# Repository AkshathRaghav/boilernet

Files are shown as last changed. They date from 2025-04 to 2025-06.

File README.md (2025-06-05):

# BoilerNet: A Compute-Enabled Mini-NAS

<div align="center" style="display: flex; justify-content: center; align-items: center; gap: 1rem;">
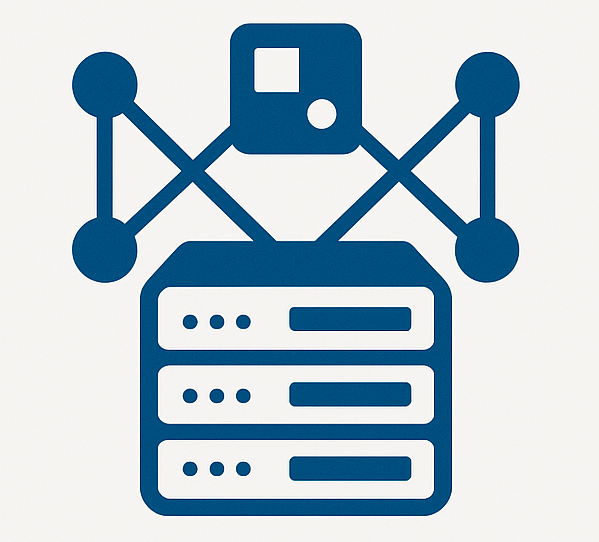
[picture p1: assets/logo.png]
  
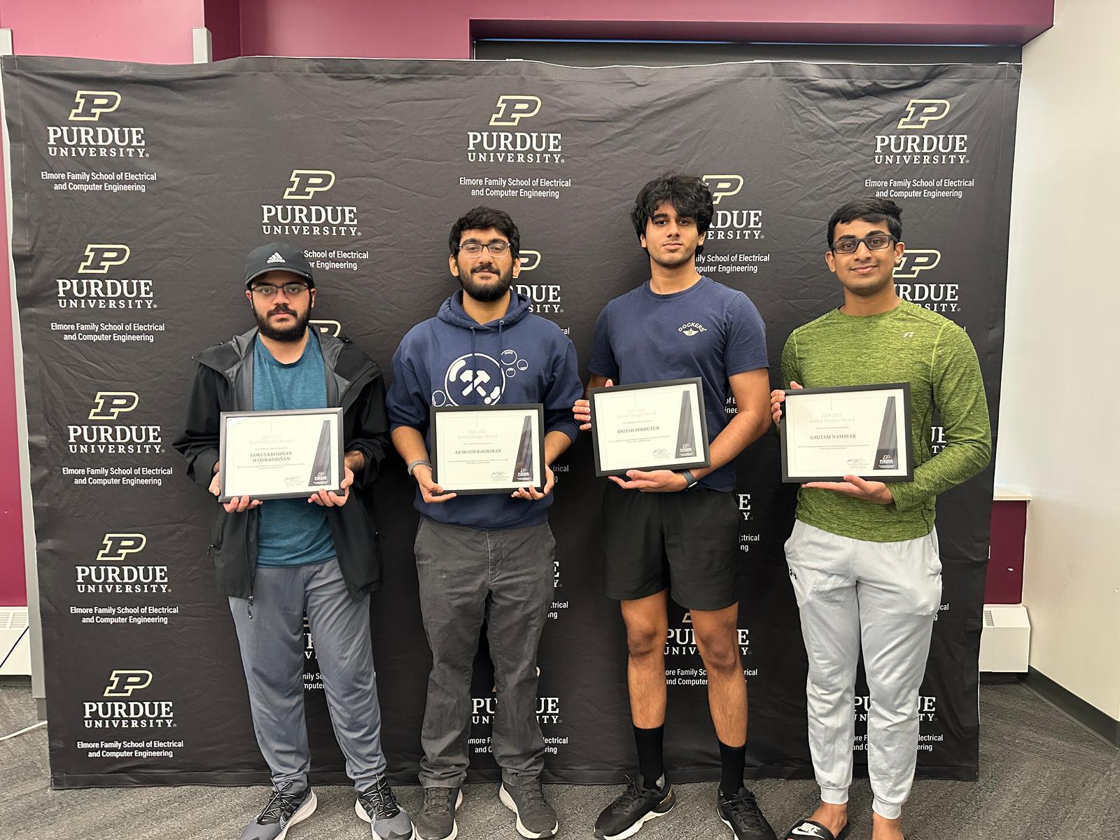
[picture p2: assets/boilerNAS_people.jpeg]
people
  
</div>

<div class="caption" align="center">
    BoilerNet Team 20! 
    From L to R: Gokulkrishnan Harikrishnan, Akshath Raghav Ravikiran, Aneesh Reddy Poddutur, Gautum Kottayil Nambiar
</div>

## Overview 

This project aimed to develop a Network Attached Storage utilizing ESP32 MCUs. The aptly-named BoilerNet aims to enable In-Network-compute alongside swappable disks and compute workloads, neatly brought together by a cloud-hosted Dashboard interface. There are a few core ideas that form the foundation for this ”cluster” – Low Power Usage, Plug-and-Play Workloads, High Scalability.

> Our reports/presentations are linked in the [/docs](./docs/). They contain in-depth views, reasonings and explanations regarding the design and its motivation. We also outline how we tested and ensured functionality. **This repository is just meant to help anyone who wishes to "refer" to our code/designs for their own use-case.**

> Watch the Demo that won us the "Senior Design Award" for Spring '25 through Purdue ECE: [Link](https://www.youtube.com/watch?v=jUlh9KClEwE)!

<div style="display: flex; justify-content: center; align-items: center; gap: 1rem;">
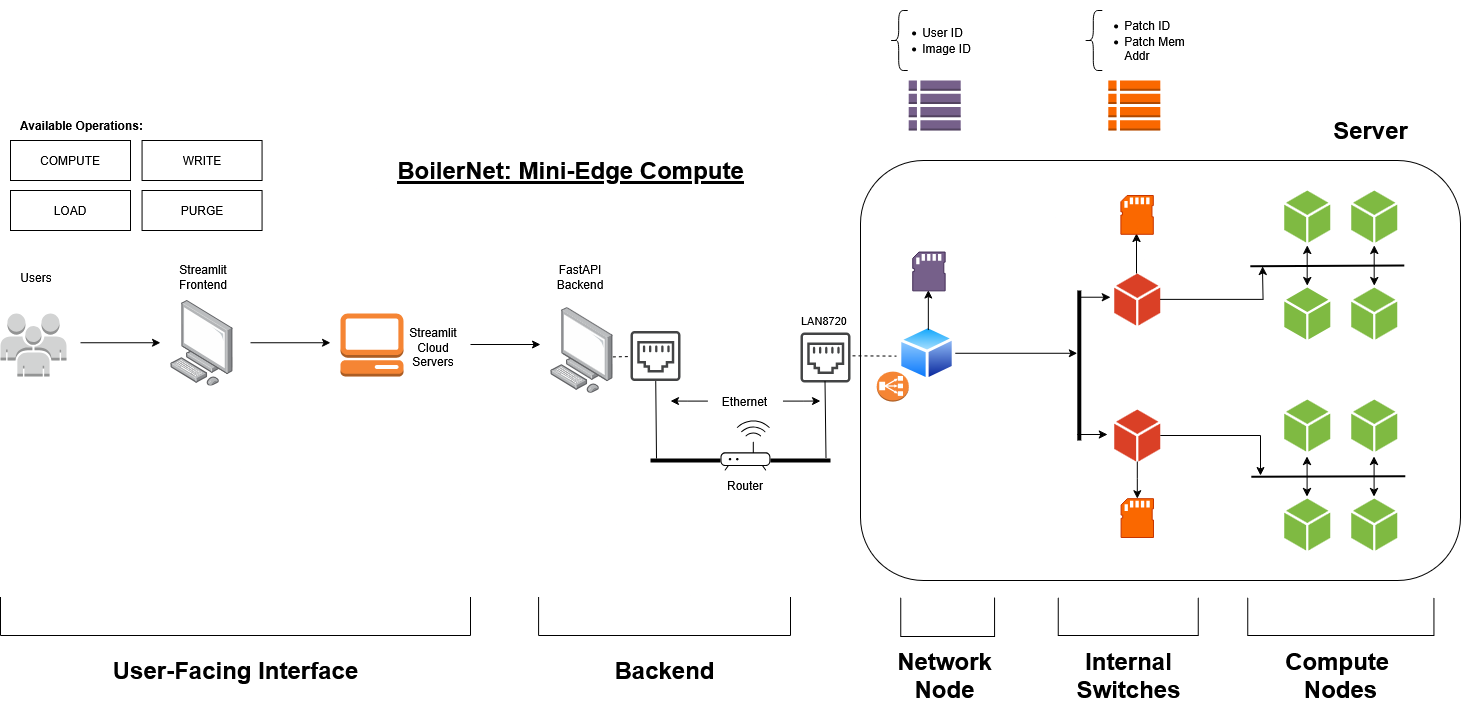
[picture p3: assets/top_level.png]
  
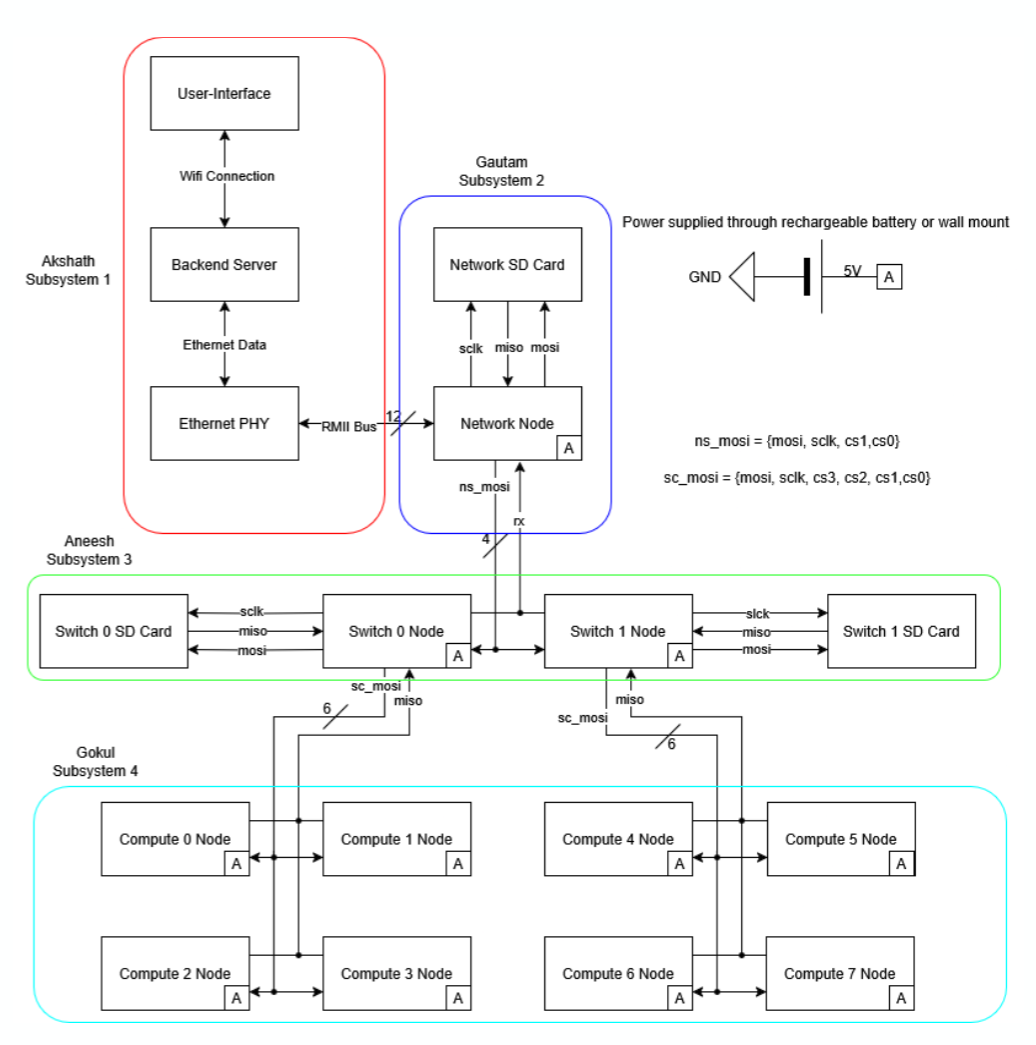
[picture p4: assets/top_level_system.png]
  
</div>
<div class="caption" align="center">
    Top Level System Diagrams
</div>

## Mechanical Design

The physical enclosure consists of six piece types, along with an optional divider: 1x Enclosure Lid, 1x Enclosure Base, 8x compute Enclosures, 8x compute Enclosure Lids, 6x
3mm diameter - 20mm screws, 4x 3mm diameter - 5 mm screws. You can find the related CAD files at [/cad/](./cad/) w/o dependencies. Reach out to [Aneesh Poddutur](https://www.linkedin.com/in/aneesh-poddutur/) for more information. 

<div align="center">
  first
  <caption> 
</div>
<div class="caption" align="center">
    Physical Enclosure
</div>

<div align="center">
  second
</div>
<div class="caption" align="center">
    Top Enclosure
</div>

<div align="center">
  third
</div>
<div class="caption" align="center">
    Compute Enclosure
</div>

<div align="center">
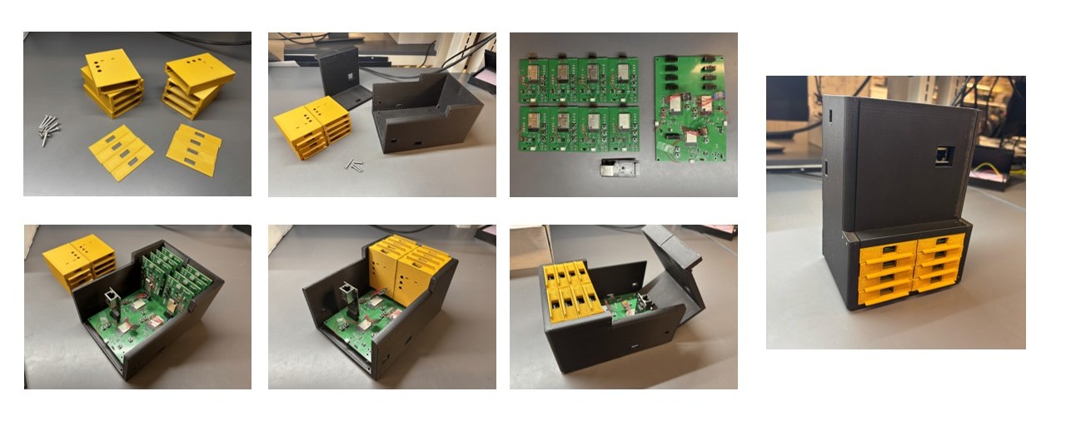
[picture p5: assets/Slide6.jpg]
  
</div>
<div class="caption" align="center">
    Assembled System!
</div>

## PCB Design

This was our first time working on PCB Design, and had a few fly-wires hanging about. Below is one of the slides we usd in our [Final Presentation](/docs/Final%20Design%20Review.pdf) to sound endearing ;)

You can find our PCB Designs at [/gerbers/](./gerbers/) and [/kicad_projects](./kicad_projects/)! Reach out to [Gautam Nambiar](https://www.linkedin.com/in/gautam-nambiar-821479251/) and [Gokul Harikrishnan](https://www.linkedin.com/in/gokulkrishnan-harikrishnan-40334b227/) if you have any questions.

<div align="center">
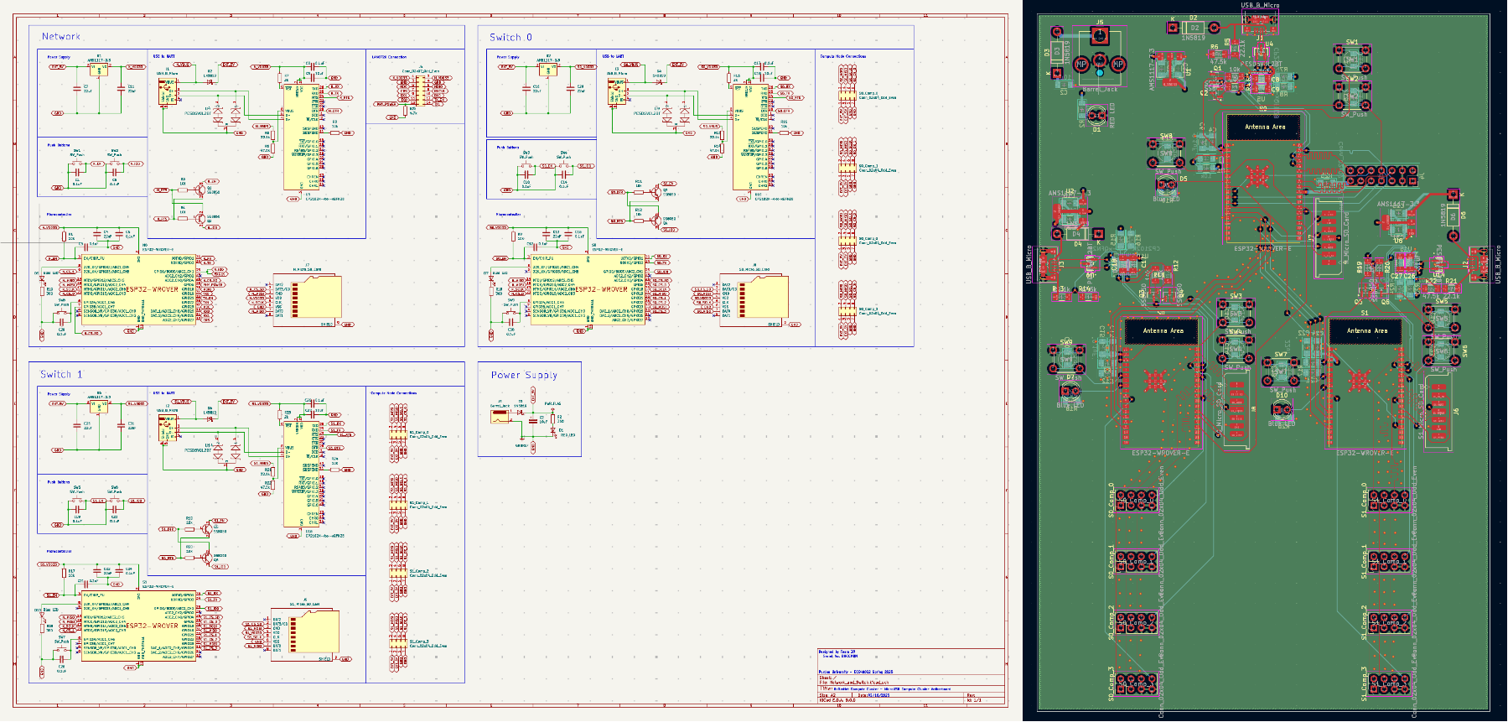
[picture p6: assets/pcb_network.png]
  
</div>
<div class="caption" align="center">
    Network/Switch PCB
</div>

<div align="center">
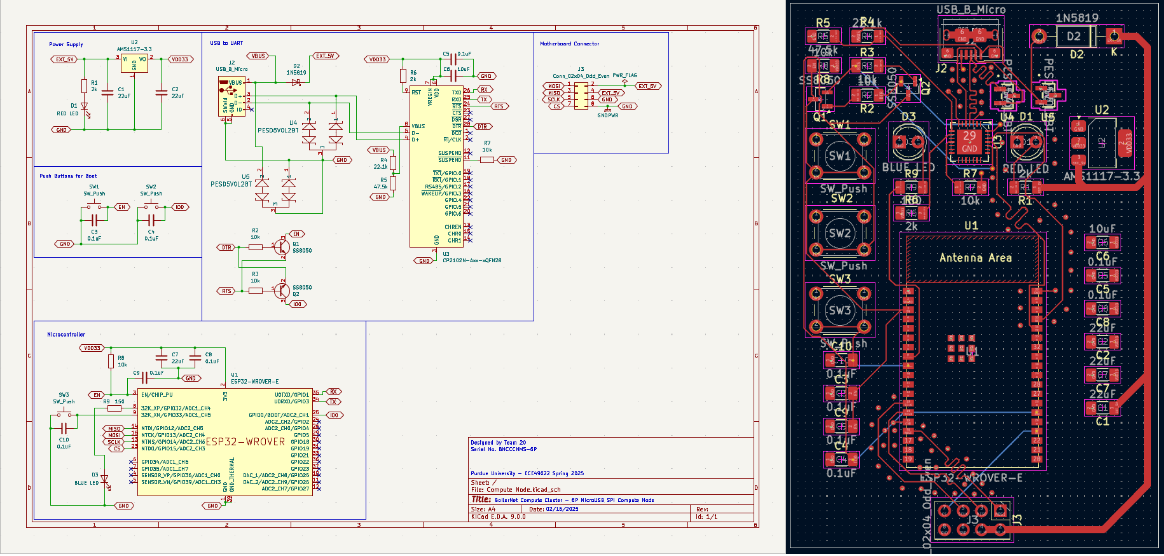
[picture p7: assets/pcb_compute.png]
  
</div>
<div class="caption" align="center">
    Compute Node PCB
</div>

<div align="center">
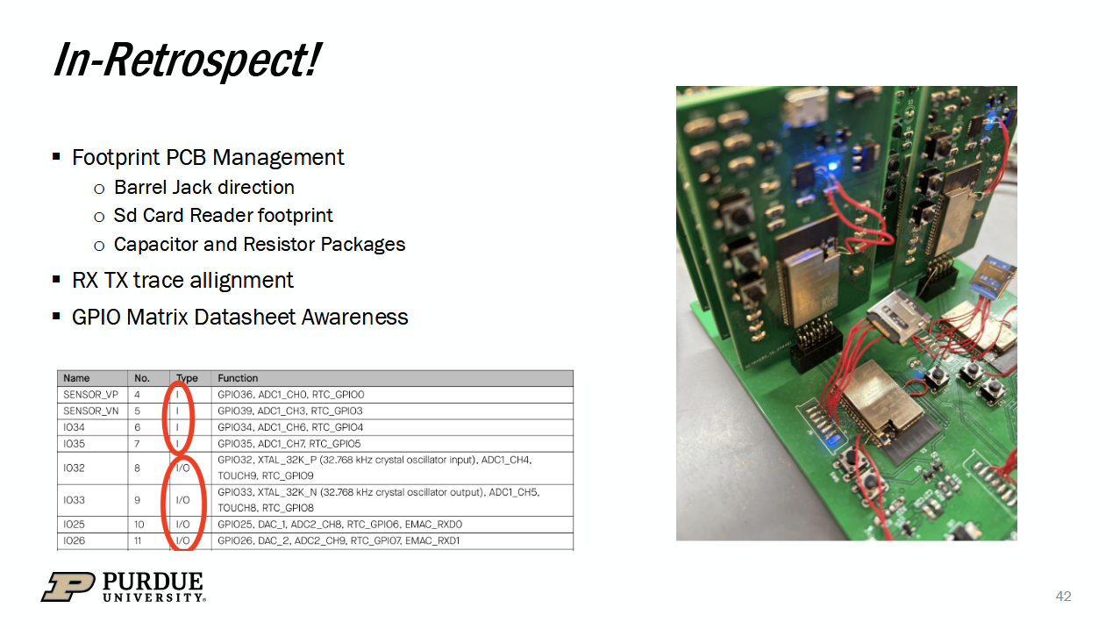
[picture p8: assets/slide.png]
  
</div>
<div class="caption" align="center">
    Mishaps/Learnings!
</div>

## Software 

All the code for the MCUs are maintained within the [/src](./src/) folder. Each node's build is maintained within it's own ESP-IDF setup, and can be configured in isolation. 
[/model_train](./model_train/) contains the code for training the models and preparing weights to flashed through [./compute_nodes](./src/compute_nodes/). Please reach out to [Akshath Raghav](https://www.linkedin.com/in/akshathrr/) if you have any questions!

- [/src/fastapi_backend](./src/fastapi_backend/) and [/src/streamlit_frontend](./src/streamlit_frontend/) can be configured using the Makefiles. Try `make venv; make setup; make run`. 
- [/src/network_node](./src/network_node/), [/src/switch_nodes](./src/switch_nodes/) and [/src/compute_nodes](./src/compute_nodes/) require `idf.py` configured and `IDF_PATH` set up. Remember, `idf.py` should be run in an ESP-IDF project directory, i.e., a directory containing a CMakeLists.txt file. `idf.py fullclean; idf.py build; idf.py flash -port /dev/ttyUSB1` will be sufficient. 
- [/model_train/extract.sh](./model_train/extract.sh) has the script for setting up ImageNet -- only if you want to train your own subsets. Thanks to [BIGBALLON](https://gist.github.com/BIGBALLON) for this [script](https://gist.github.com/BIGBALLON/8a71d225eff18d88e469e6ea9b39cef4). 
- [/model_train/train.py](./model_train/train.py) and [/model_train/convert_and_header.py](./model_train/convert_and_header.py) will set you up quickly with training your MobileNet or EfficientNet backbones with a head for the subset you've chosen, and then quantizing them (w/ additional calibration tuning). Results will be put into [/model_train/models](./model_train/models/) and [/model_train/quantized_models](./model_train/quantized_models/). After you're done training, put the chosen header (.cc) file into [/src/compute_nodes/main](./src/compute_nodes/main/) and put this file name into Line 5 in [/src/compute_nodes/main/CMakeLists.txt](/src/compute_nodes/main/CMakeLists.txt). 

---

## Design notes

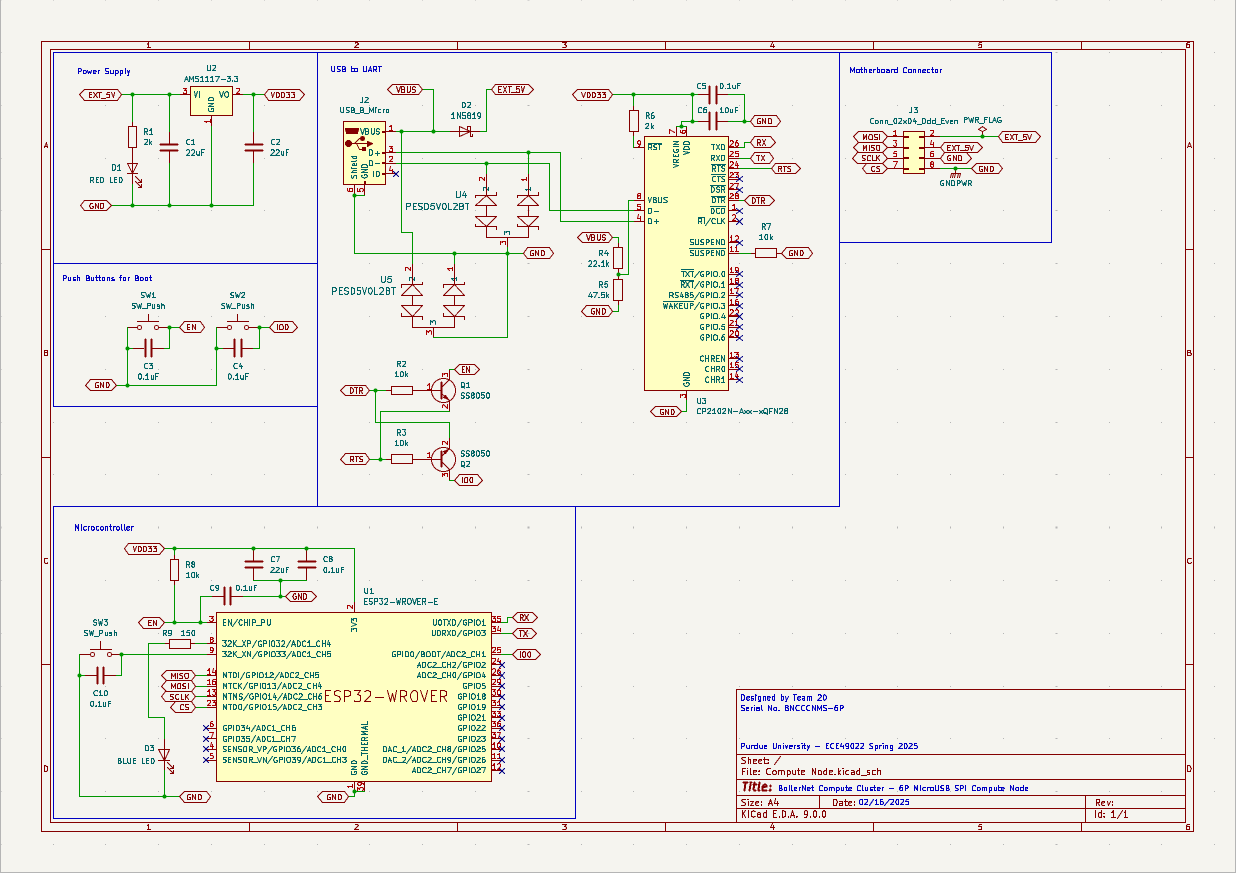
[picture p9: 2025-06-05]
assets/compute.PNG

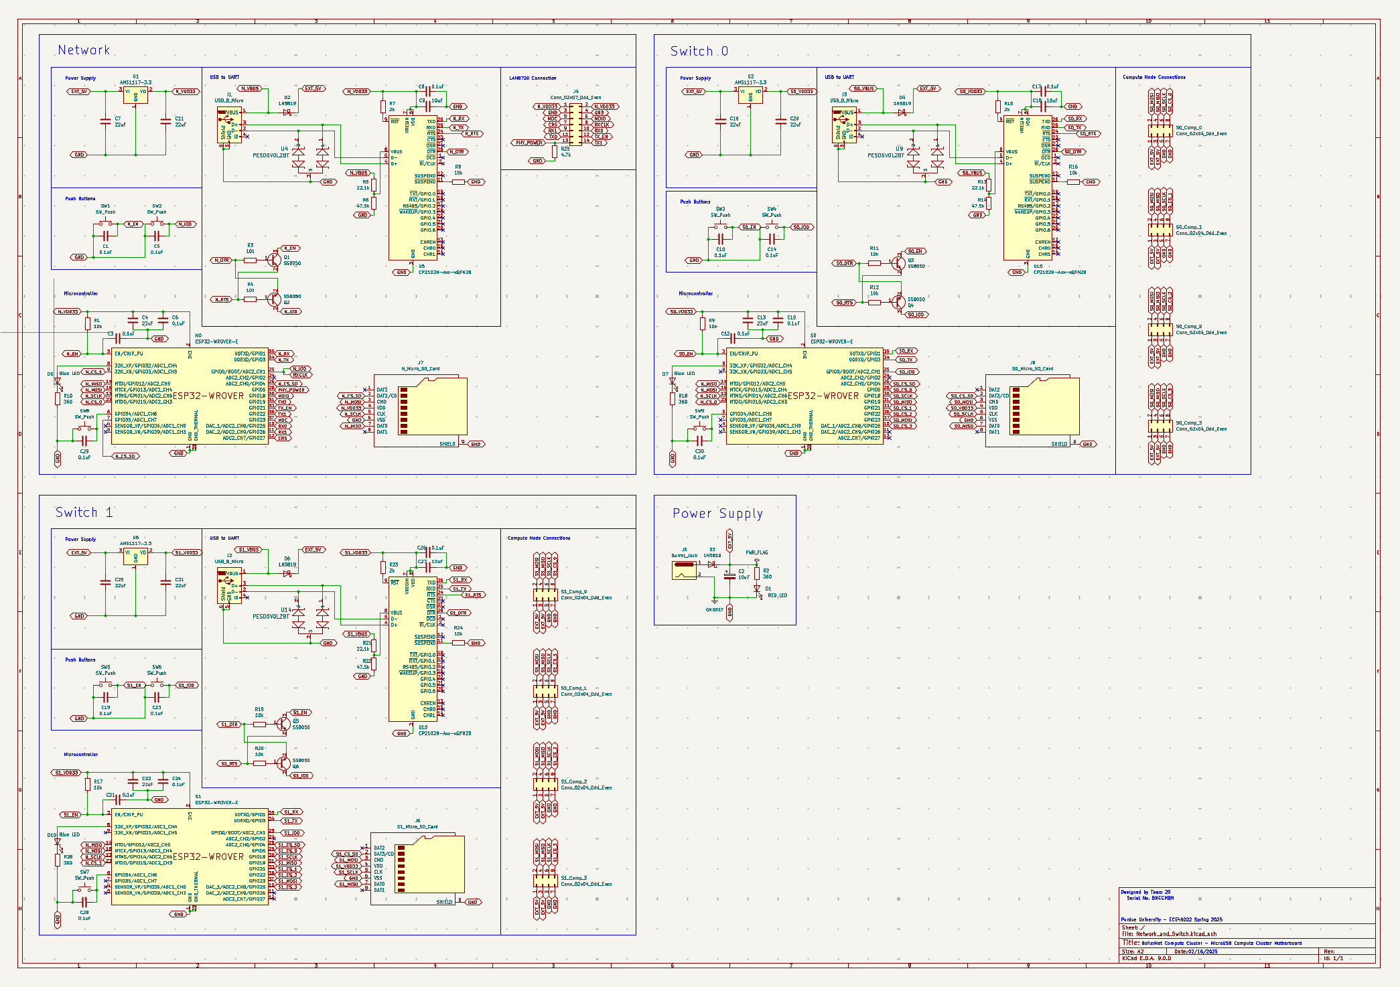
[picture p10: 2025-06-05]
assets/Network_and_Switch.png

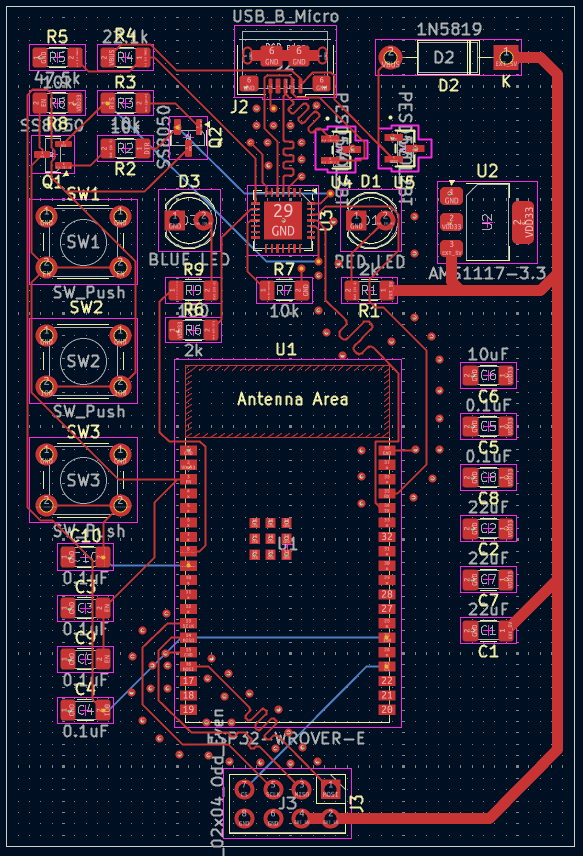
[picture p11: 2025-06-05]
assets/compute_pcb.PNG

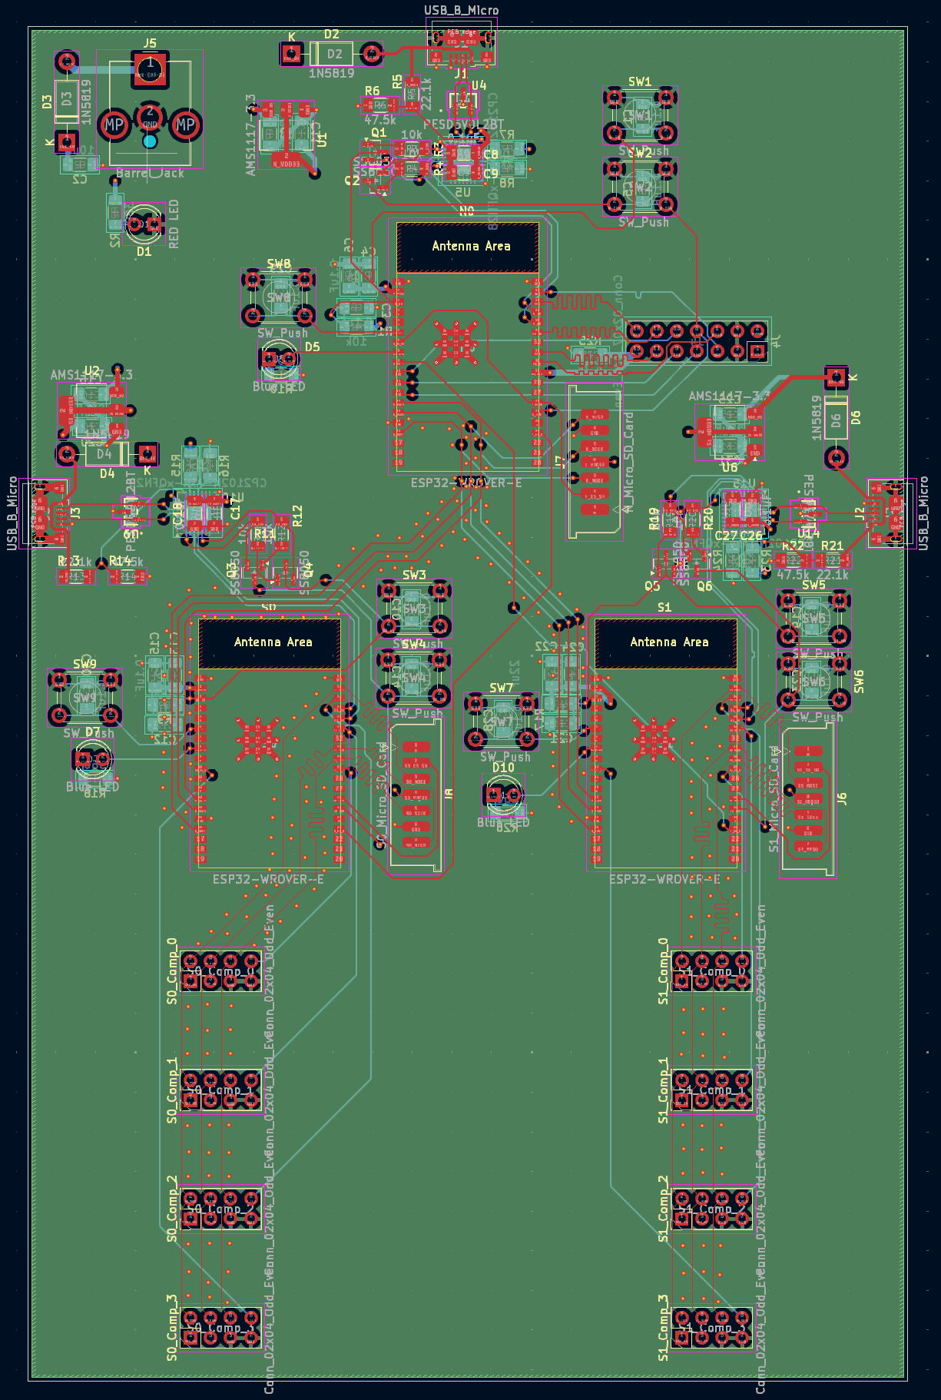
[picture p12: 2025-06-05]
assets/Network_and_Switch_pcb.png

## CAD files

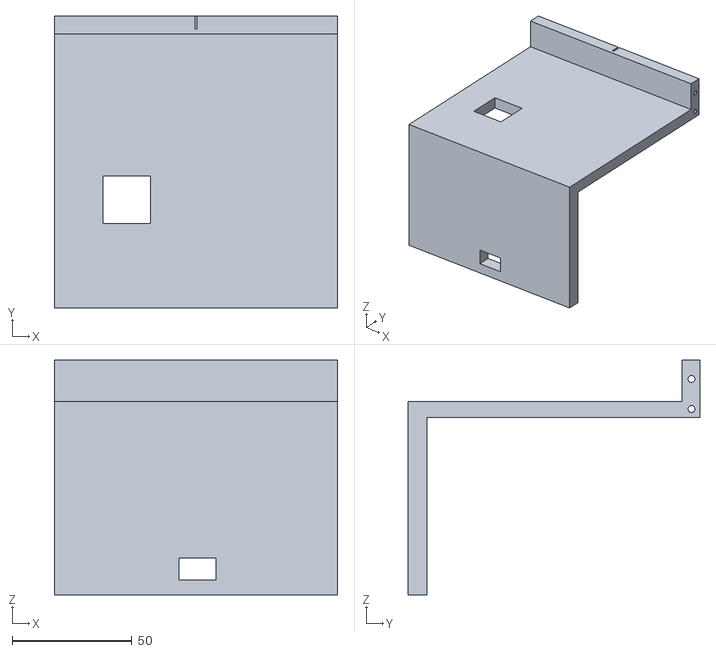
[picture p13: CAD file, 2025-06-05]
cad/STL/Main Enclosure Lid Part.stl
118.3 x 122.0 x 98.2

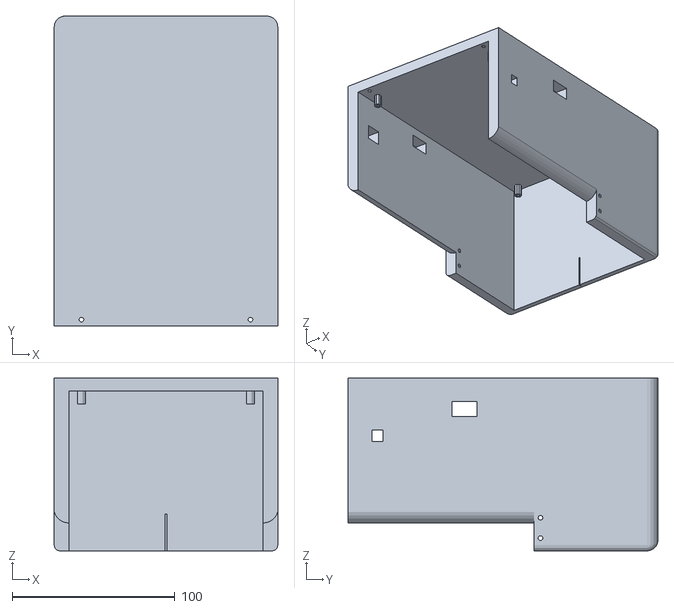
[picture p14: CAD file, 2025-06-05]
cad/STL/Main Enclosure Bottom.stl
137.6 x 190.8 x 106.4

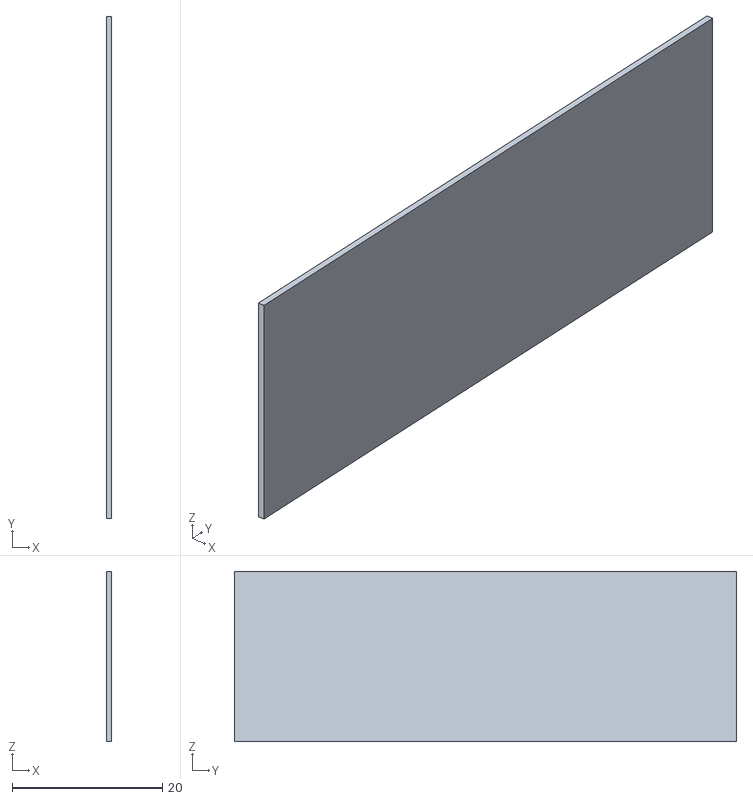
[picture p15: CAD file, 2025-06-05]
cad/STL/Divider.stl
0.675 x 66.9 x 22.6

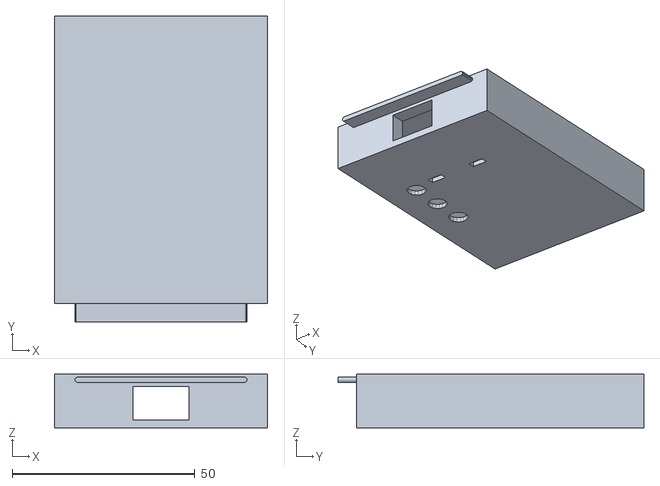
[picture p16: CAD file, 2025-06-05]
cad/STL/Compute Node Enclosure.stl
58.4 x 83.8 x 14.8

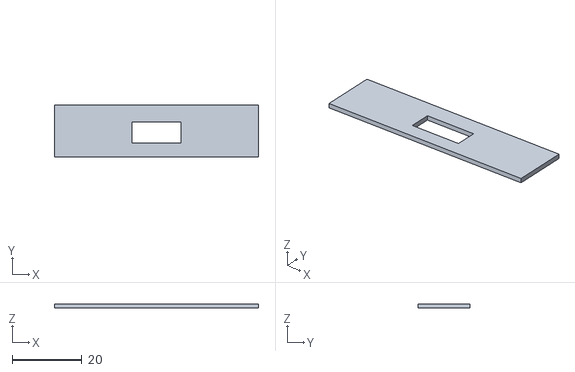
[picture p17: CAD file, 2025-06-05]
cad/STL/Compute Node Lid.stl
58.4 x 14.8 x 1.20

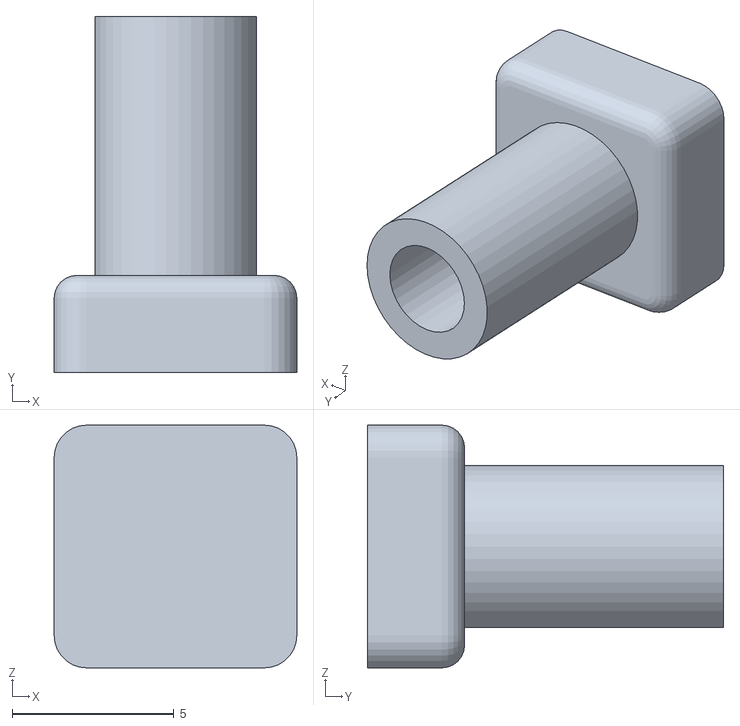
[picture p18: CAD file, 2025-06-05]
cad/STL/Test Screw Hole.stl
7.50 x 11.0 x 7.50

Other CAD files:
cad/Assemblies/Compute Node Assembly.iam
cad/Parts/LAN Board Part.ipt
cad/Parts/Long Female Plug Part.ipt

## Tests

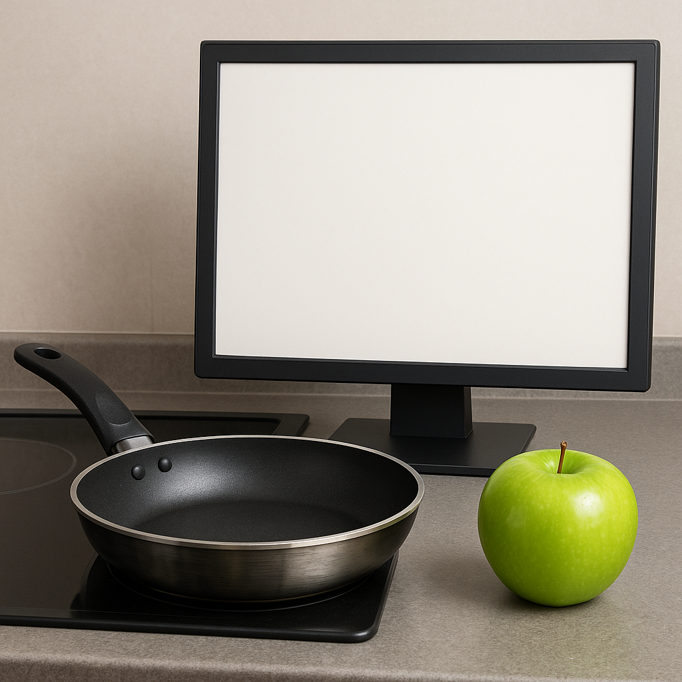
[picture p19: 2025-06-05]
test/input/monitor_frypan.png

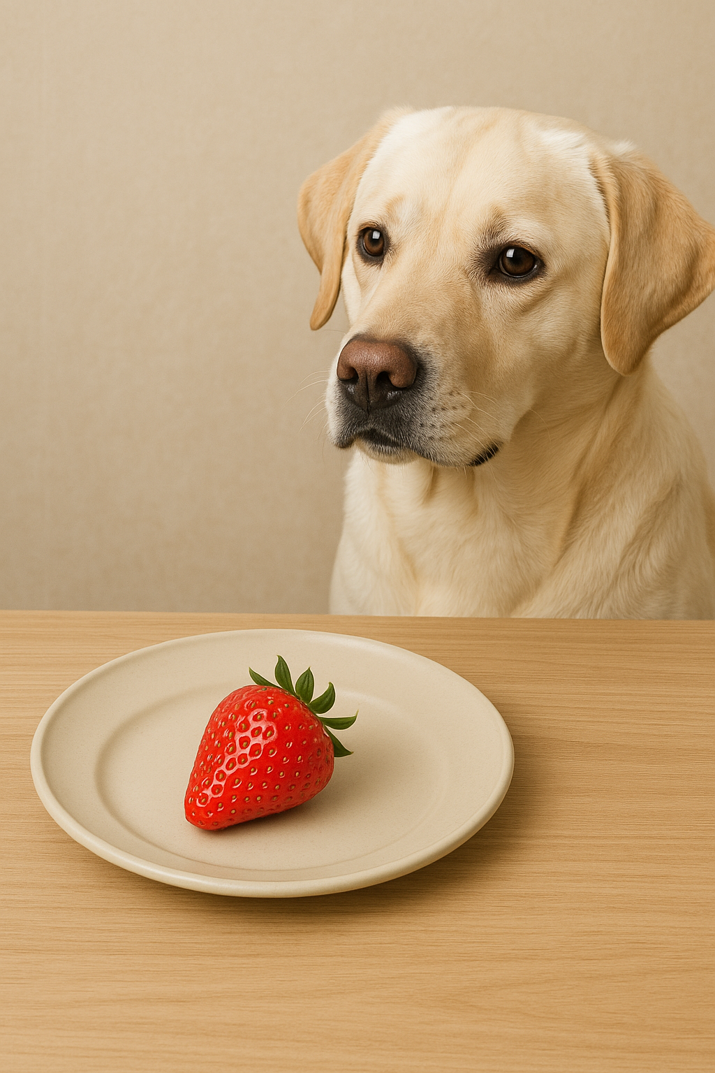
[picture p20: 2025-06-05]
test/input/dog_straw_plate.png

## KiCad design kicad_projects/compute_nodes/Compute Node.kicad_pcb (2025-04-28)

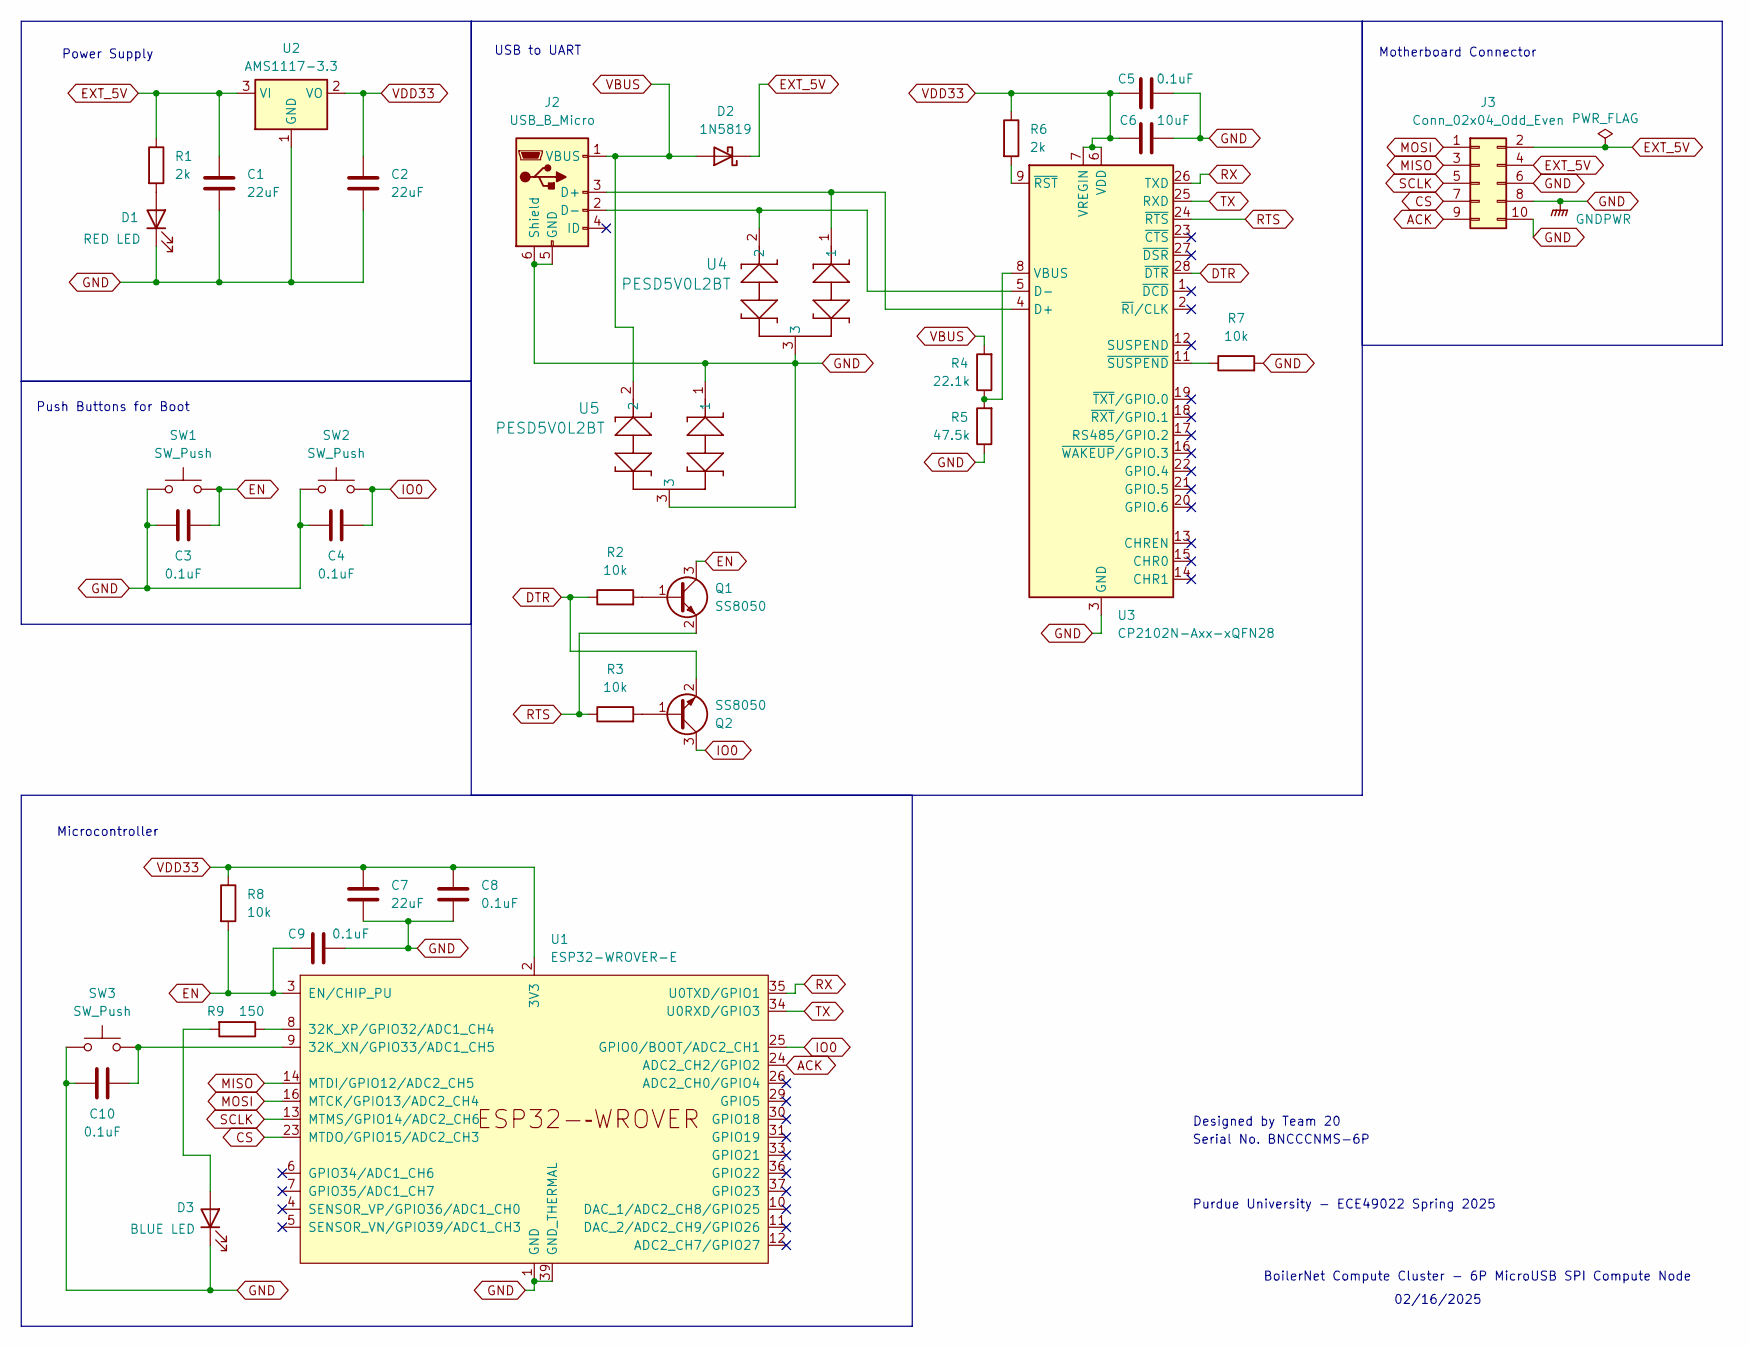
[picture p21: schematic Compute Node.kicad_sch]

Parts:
C1, C2, C7: 22uF; C_1206_3216Metric_Pad1.33x1.80mm_HandSolder
C3, C4, C5, C8, C9, C10: 0.1uF; C_1206_3216Metric_Pad1.33x1.80mm_HandSolder
C6: 10uF; C_1206_3216Metric_Pad1.33x1.80mm_HandSolder
D1: RED LED; LED_D4.0mm
D2: 1N5819; D_DO-41_SOD81_P10.16mm_Horizontal
D3: BLUE LED; LED_D4.0mm
J2: USB_B_Micro; USB_Micro-B_Amphenol_10118193-0002LF_Horizontal
J3: Conn_02x04_Odd_Even; PinHeader_2x05_P2.54mm_Horizontal
Q1, Q2: SS8050; SOT-23
R1, R6: 2k; R_1206_3216Metric_Pad1.30x1.75mm_HandSolder
R2, R3, R7, R8: 10k; R_1206_3216Metric_Pad1.30x1.75mm_HandSolder
R4: 22.1k; R_1206_3216Metric_Pad1.30x1.75mm_HandSolder
R5: 47.5k; R_1206_3216Metric_Pad1.30x1.75mm_HandSolder
R9: 150; R_1206_3216Metric_Pad1.30x1.75mm_HandSolder
SW1, SW2, SW3: SW_Push; SW_PUSH_6mm
U1: ESP32-WROVER-E
U2: AMS1117-3.3; SOT-223-3_TabPin2
U3: CP2102N-Axx-xQFN28; QFN-28-1EP_5x5mm_P0.5mm_EP3.35x3.35mm
U4, U5: PESD5V0L2BT; SOT23_NXP-M

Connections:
ACK: J3.9, U1.24 (ADC2_CH2/GPIO2)
CS: J3.7, U1.23 (MTDO/GPIO15/ADC2_CH3)
DTR: Q2.2 (E), R2.1, U3.28 (~DTR)
EN: C3.2, C9.2, Q1.3 (C), R8.2, SW1.2, U1.3 (EN/CHIP_PU)
EXT_5V: C1.1, D2.1 (K), J3.2, J3.4, R1.1, U2.3 (VI)
GND: C1.2, C2.2, C3.1, C4.1, C5.2, C6.2, C7.2, C8.2, C9.1, C10.1, D1.1 (K), D3.1 (K), J2.5 (GND), J2.6 (Shield), J3.6, J3.8, J3.10, R5.1, R7.2, SW1.1, SW2.1, SW3.1, U1.1 (GND), U1.15 (GND), U1.38 (GND), U1.39 (GND_THERMAL), U2.1 (GND), U3.3 (GND), U3.29 (GND), U4.3, U5.1, U5.3
IO0: C4.2, Q2.3 (C), SW2.2, U1.25 (GPIO0/BOOT/ADC2_CH1)
MISO: J3.3, U1.14 (MTDI/GPIO12/ADC2_CH5)
MOSI: J3.1, U1.16 (MTCK/GPIO13/ADC2_CH4)
unnamed: D1.2 (A), R1.2
unnamed: D3.2 (A), R9.2
unnamed: J2.3 (D+), U3.4 (D+), U4.1
unnamed: J2.2 (D-), U3.5 (D-), U4.2
unnamed: Q1.1 (B), R2.2
unnamed: Q2.1 (B), R3.2
unnamed: C10.2, SW3.2, U1.9 (32K_XN/GPIO33/ADC1_CH5)
unnamed: R9.1, U1.8 (32K_XP/GPIO32/ADC1_CH4)
unnamed: R4.1, R5.2, U3.8 (VBUS)
unnamed: R6.2, U3.9 (~RST)
unnamed: R7.1, U3.11 (~SUSPEND)
RTS: Q1.2 (E), R3.1, U3.24 (~RTS)
RX: U1.35 (U0TXD/GPIO1), U3.26 (TXD)
SCLK: J3.5, U1.13 (MTMS/GPIO14/ADC2_CH6)
TX: U1.34 (U0RXD/GPIO3), U3.25 (RXD)
VBUS: D2.2 (A), J2.1 (VBUS), R4.2, U5.2
VDD33: C2.1, C5.1, C6.1, C7.1, C8.1, R6.1, R8.1, U1.2 (3V3), U2.2 (VO), U3.6 (VDD), U3.7 (VREGIN)

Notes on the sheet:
Designed by Team 20
Motherboard Connector
Purdue University - ECE49022 Spring 2025
Microcontroller
USB to UART
Serial No. BNCCCNMS-6P
02/16/2025
Push Buttons for Boot
Power Supply
BoilerNet Compute Cluster - 6P MicroUSB SPI Compute Node

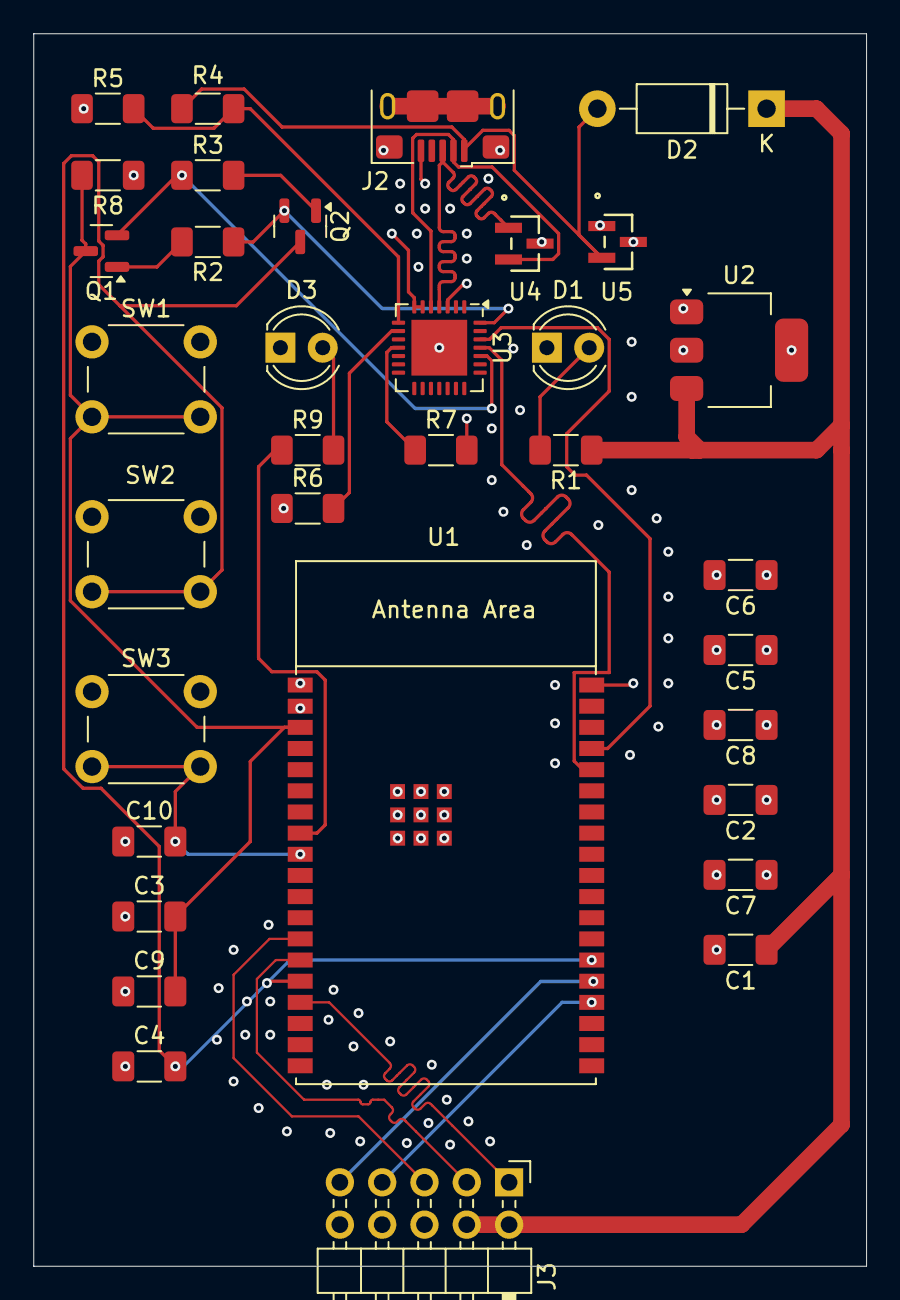
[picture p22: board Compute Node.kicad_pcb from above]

Board: 4 copper layers, 50.0 x 74.0 mm, 34 parts (0 on the bottom side), 26 nets.

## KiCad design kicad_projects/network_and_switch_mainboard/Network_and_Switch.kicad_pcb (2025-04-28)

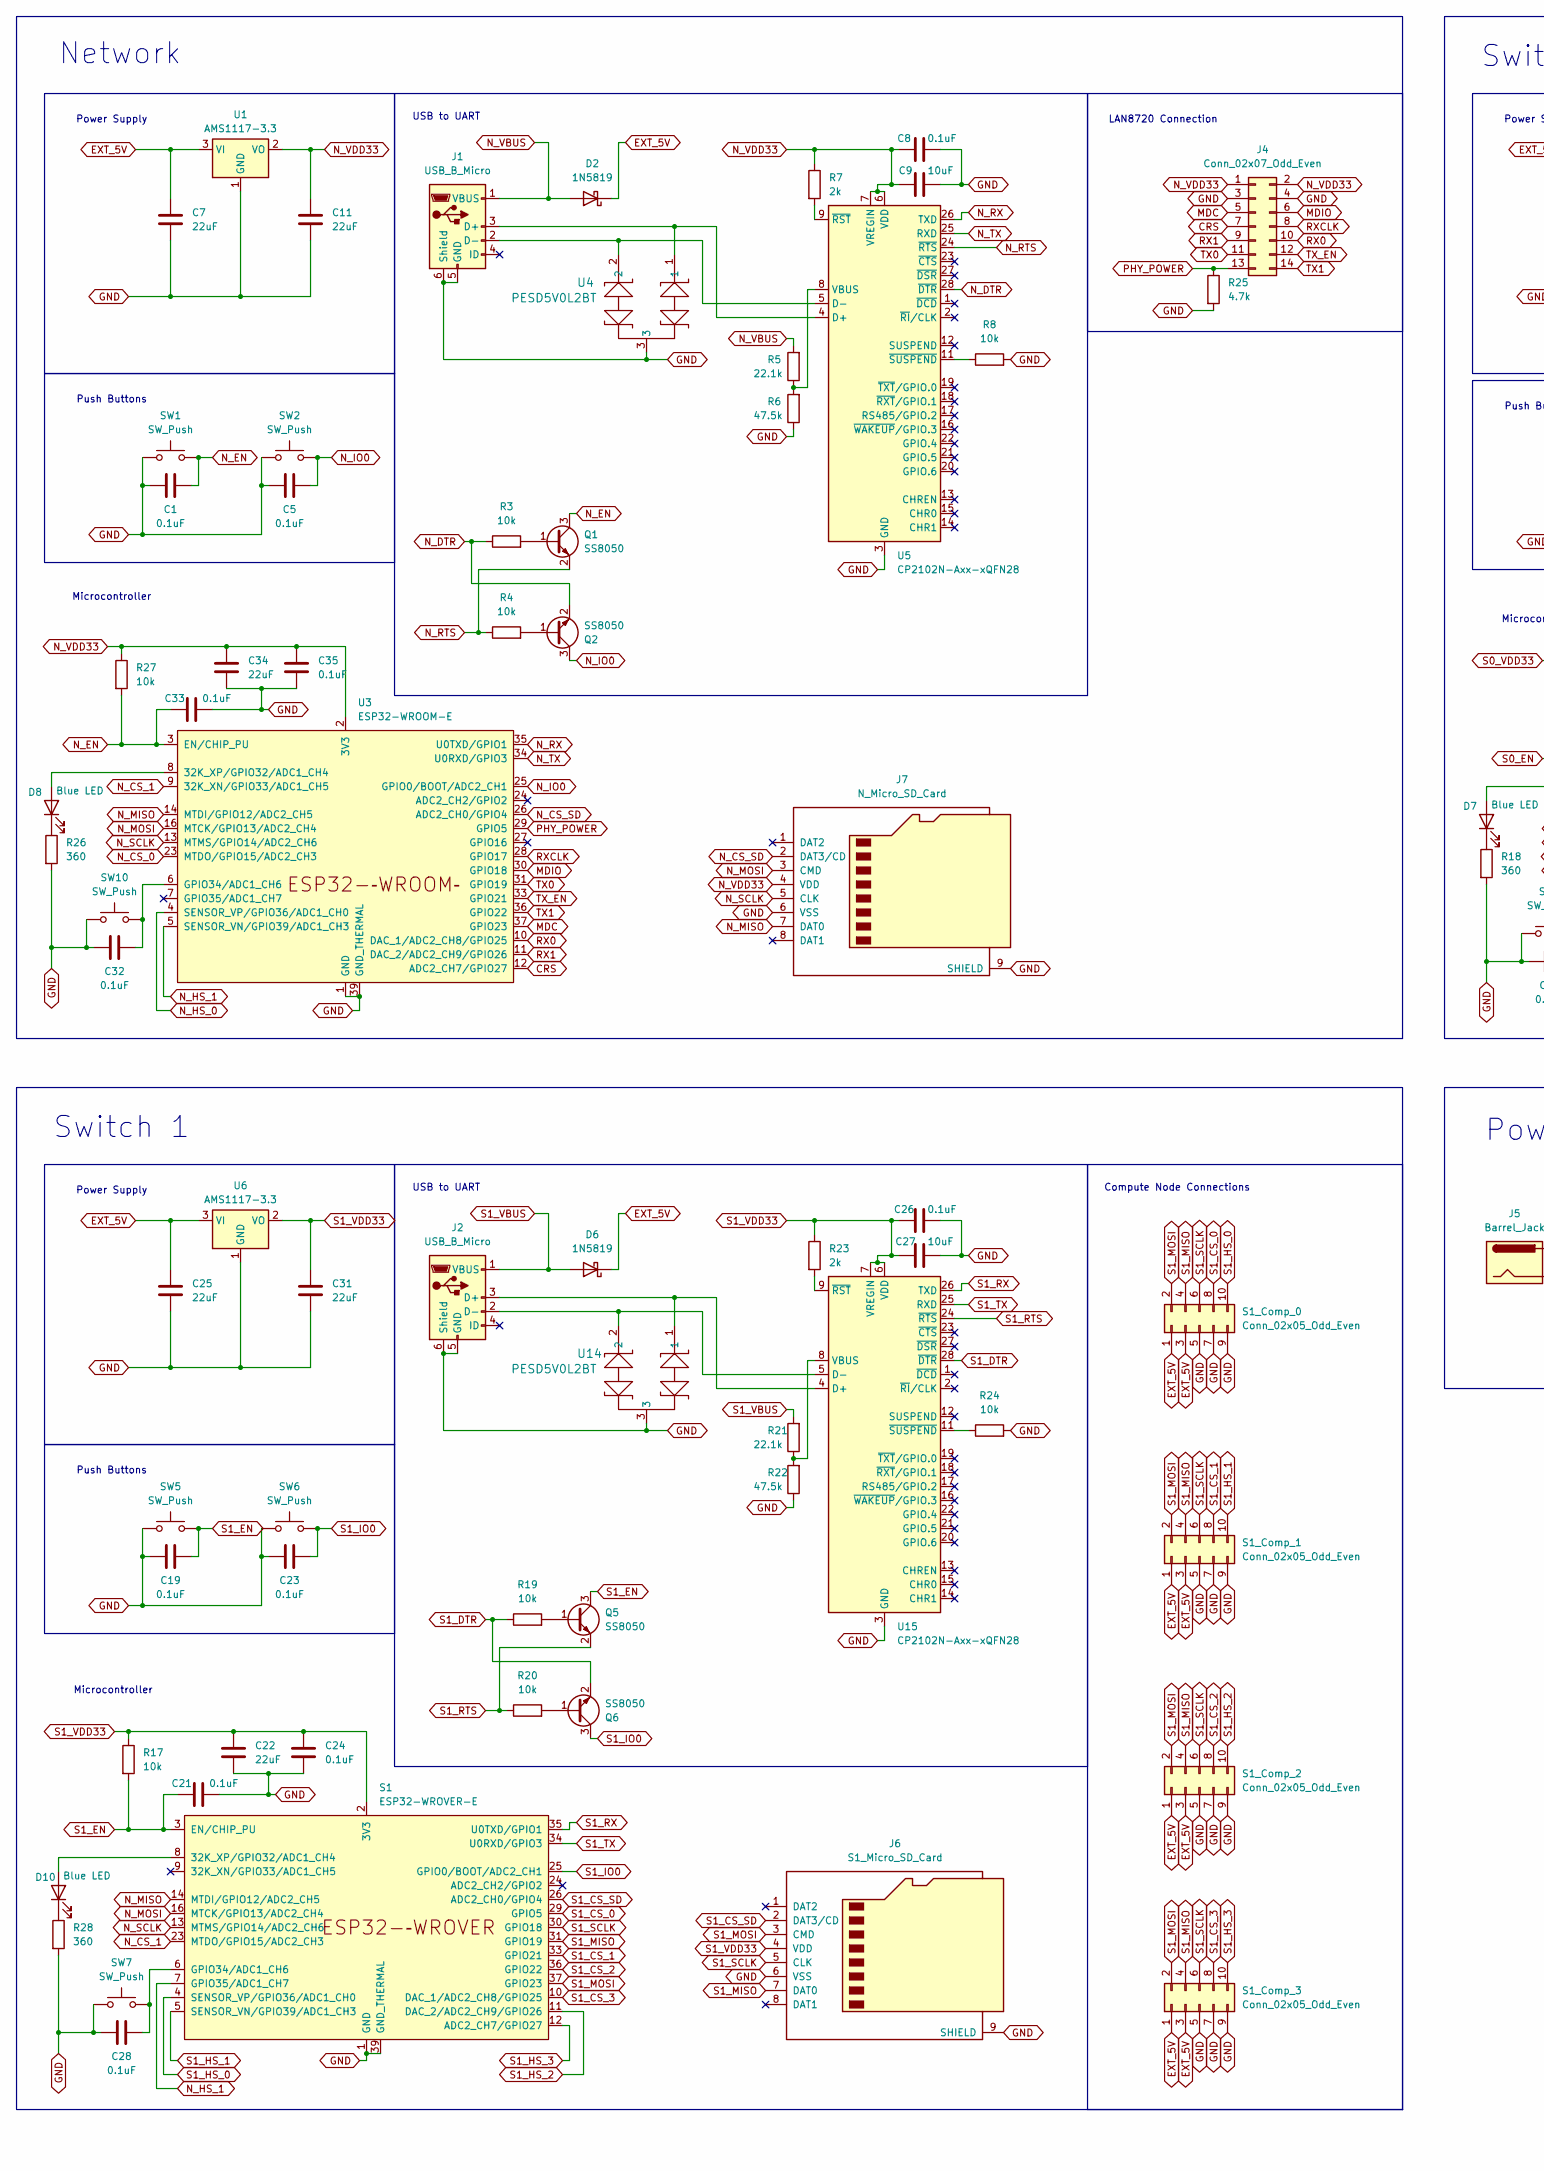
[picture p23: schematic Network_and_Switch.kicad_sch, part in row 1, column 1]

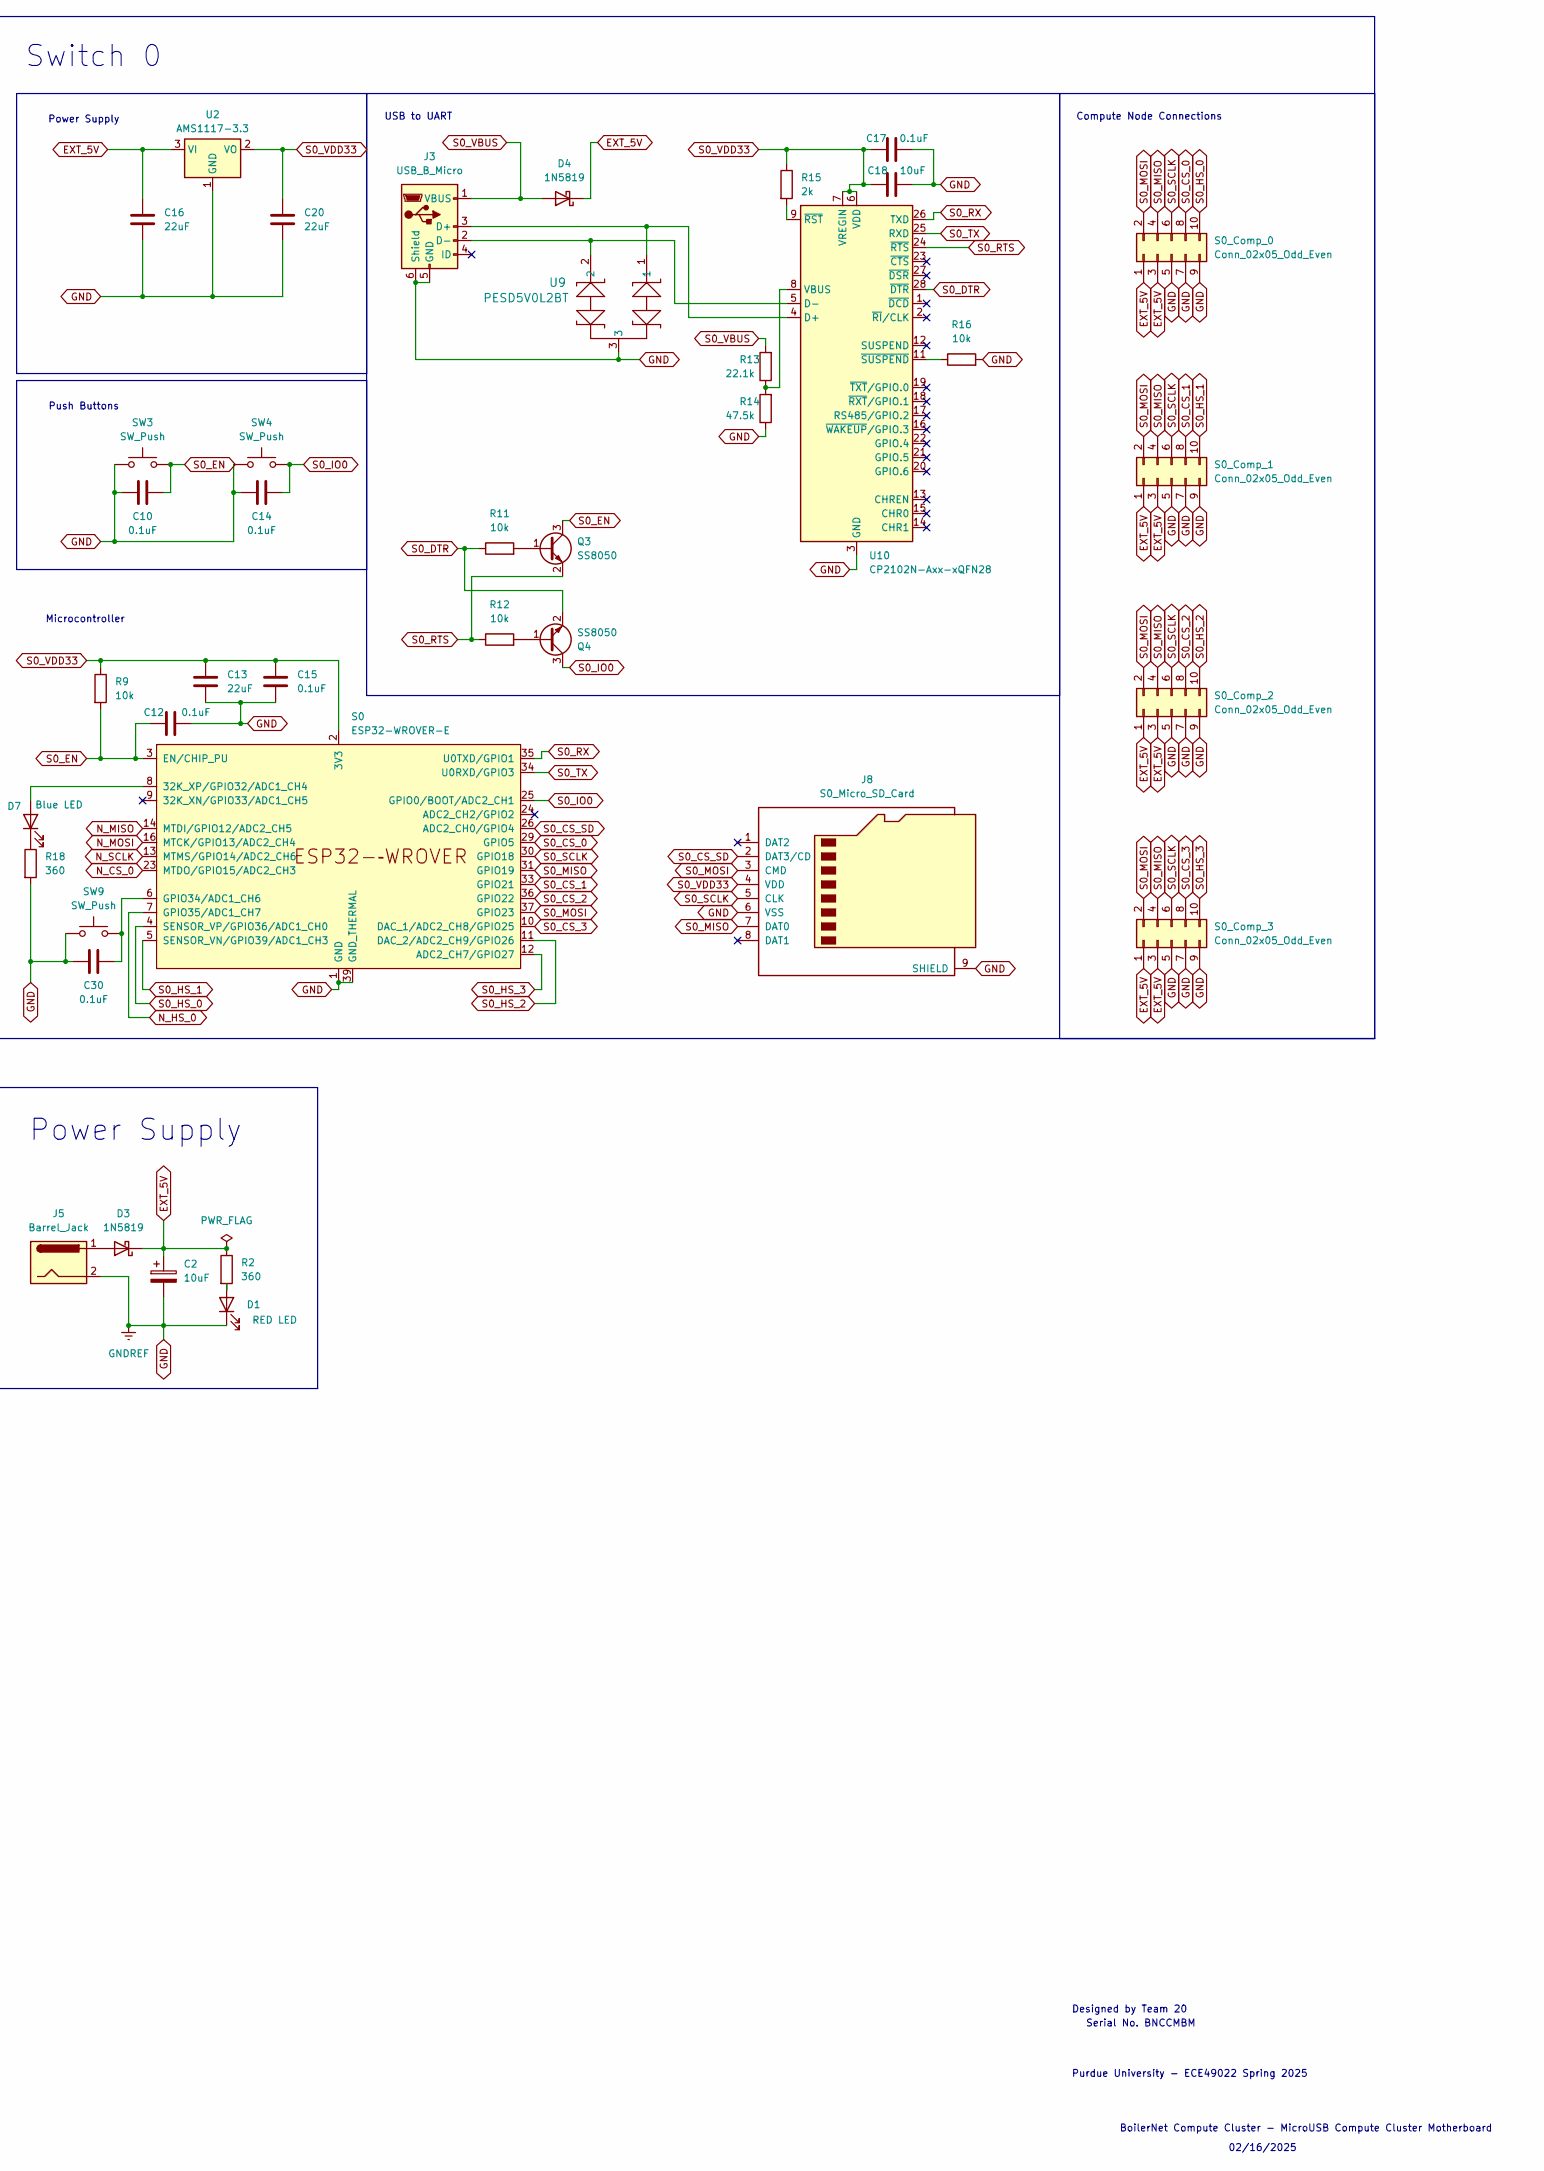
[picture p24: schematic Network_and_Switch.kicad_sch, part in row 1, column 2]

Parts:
C1, C5, C8, C10, C12, C14, C15, C17, C19, C21, C23, C24, C26, C28, C30, C32, C33, C35: 0.1uF; C_1206_3216Metric_Pad1.33x1.80mm_HandSolder
C2, C9, C18, C27: 10uF; C_1206_3216Metric_Pad1.33x1.80mm_HandSolder
C7, C11, C13, C16, C20, C22, C25, C31, C34: 22uF; C_1206_3216Metric_Pad1.33x1.80mm_HandSolder
D1: RED LED; LED_D4.0mm
D2, D3, D4, D6: 1N5819; D_DO-41_SOD81_P10.16mm_Horizontal
D7, D8, D10: Blue LED; LED_D4.0mm
J1, J2, J3: USB_B_Micro; USB_Micro-B_Amphenol_10118193-0002LF_Horizontal
J4: Conn_02x07_Odd_Even; PinHeader_2x07_P2.54mm_Vertical
J5: Barrel_Jack; BarrelJack_CUI_PJ-063AH_Horizontal_CircularHoles
J6: S1_Micro_SD_Card; Samtec_UMPS-07-XX.X-X-V-S_1x07_P2.0mm_Socket
J7: N_Micro_SD_Card; Samtec_UMPS-07-XX.X-X-V-S_1x07_P2.0mm_Socket
J8: S0_Micro_SD_Card; Samtec_UMPS-07-XX.X-X-V-S_1x07_P2.0mm_Socket
Q1, Q2, Q3, Q4, Q5, Q6: SS8050; SOT-23
R2, R18, R26, R28: 360; R_1206_3216Metric_Pad1.30x1.75mm_HandSolder
R3, R4, R8, R9, R11, R12, R16, R17, R19, R20, R24, R27: 10k; R_1206_3216Metric_Pad1.30x1.75mm_HandSolder
R5, R13, R21: 22.1k; R_1206_3216Metric_Pad1.30x1.75mm_HandSolder
R6, R14, R22: 47.5k; R_1206_3216Metric_Pad1.30x1.75mm_HandSolder
R7, R15, R23: 2k; R_1206_3216Metric_Pad1.30x1.75mm_HandSolder
R25: 4.7k; R_1206_3216Metric_Pad1.30x1.75mm_HandSolder
S0, S1: ESP32-WROVER-E
S0_Comp_0, S0_Comp_1, S0_Comp_2, S0_Comp_3, S1_Comp_0, S1_Comp_1, S1_Comp_2, S1_Comp_3: Conn_02x05_Odd_Even; PinHeader_2x05_P2.54mm_Vertical
SW1, SW2, SW3, SW4, SW5, SW6, SW7, SW9, SW10: SW_Push; SW_PUSH_6mm
U1, U2, U6: AMS1117-3.3; SOT-223-3_TabPin2
U3: ESP32-WROOM-E; ESP32-WROOM-32E
U4, U9, U14: PESD5V0L2BT; SOT23_NXP-M
U5, U10, U15: CP2102N-Axx-xQFN28; QFN-28-1EP_5x5mm_P0.5mm_EP3.35x3.35mm

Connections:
CRS: J4.7, U3.12 (ADC2_CH7/GPIO27)
EXT_5V: C2.1, C7.1, C16.1, C25.1, D2.1 (K), D3.1 (K), D4.1 (K), D6.1 (K), R2.1, S0_Comp_0.1, S0_Comp_0.3, S0_Comp_1.1, S0_Comp_1.3, S0_Comp_2.1, S0_Comp_2.3, S0_Comp_3.1, S0_Comp_3.3, S1_Comp_0.1, S1_Comp_0.3, S1_Comp_1.1, S1_Comp_1.3, S1_Comp_2.1, S1_Comp_2.3, S1_Comp_3.1, S1_Comp_3.3, U1.3 (VI), U2.3 (VI), U6.3 (VI)
GND: C1.1, C2.2, C5.1, C7.2, C8.2, C9.2, C10.1, C11.2, C12.1, C13.2, C14.1, C15.2, C16.2, C17.2, C18.2, C19.1, C20.2, C21.1, C22.2, C23.1, C24.2, C25.2, C26.2, C27.2, C28.1, C30.1, C31.2, C32.1, C33.1, C34.2, C35.2, D1.1 (K), J1.5 (GND), J1.6 (Shield), J2.5 (GND), J2.6 (Shield), J3.5 (GND), J3.6 (Shield), J4.3, J4.4, J5.2, J6.6 (VSS), J6.9 (SHIELD), J7.6 (VSS), J7.9 (SHIELD), J8.6 (VSS), J8.9 (SHIELD), R6.1, R8.2, R14.1, R16.2, R18.2, R22.1, R24.2, R25.2, R26.2, R28.2, S0.1 (GND), S0.15 (GND), S0.38 (GND), S0.39 (GND_THERMAL), S0_Comp_0.5, S0_Comp_0.7, S0_Comp_0.9, S0_Comp_1.5, S0_Comp_1.7, S0_Comp_1.9, S0_Comp_2.5, S0_Comp_2.7, S0_Comp_2.9, S0_Comp_3.5, S0_Comp_3.7, S0_Comp_3.9, S1.1 (GND), S1.15 (GND), S1.38 (GND), S1.39 (GND_THERMAL), S1_Comp_0.5, S1_Comp_0.7, S1_Comp_0.9, S1_Comp_1.5, S1_Comp_1.7, S1_Comp_1.9, S1_Comp_2.5, S1_Comp_2.7, S1_Comp_2.9, S1_Comp_3.5, S1_Comp_3.7, S1_Comp_3.9, SW1.1, SW2.1, SW3.1, SW4.1, SW5.1, SW6.1, SW7.1, SW9.1, SW10.1, U1.1 (GND), U2.1 (GND), U3.1 (GND), U3.15 (GND), U3.38 (GND), U3.39 (GND_THERMAL), U4.3, U5.3 (GND), U5.29 (GND), U6.1 (GND), U9.3, U10.3 (GND), U10.29 (GND), U14.3, U15.3 (GND), U15.29 (GND)
MDC: J4.5, U3.37 (GPIO23)
MDIO: J4.6, U3.30 (GPIO18)
N_CS_0: S0.23 (MTDO/GPIO15/ADC2_CH3), U3.23 (MTDO/GPIO15/ADC2_CH3)
N_CS_1: S1.23 (MTDO/GPIO15/ADC2_CH3), U3.9 (32K_XN/GPIO33/ADC1_CH5)
N_CS_SD: J7.2 (DAT3/CD), U3.26 (ADC2_CH0/GPIO4)
N_DTR: Q2.2 (E), R3.1, U5.28 (~DTR)
N_EN: C1.2, C33.2, Q1.3 (C), R27.2, SW1.2, U3.3 (EN/CHIP_PU)
N_HS_0: S0.7 (GPIO35/ADC1_CH7), U3.4 (SENSOR_VP/GPIO36/ADC1_CH0)
N_HS_1: S1.7 (GPIO35/ADC1_CH7), U3.5 (SENSOR_VN/GPIO39/ADC1_CH3)
N_IO0: C5.2, Q2.3 (C), SW2.2, U3.25 (GPIO0/BOOT/ADC2_CH1)
N_MISO: J7.7 (DAT0), S0.14 (MTDI/GPIO12/ADC2_CH5), S1.14 (MTDI/GPIO12/ADC2_CH5), U3.14 (MTDI/GPIO12/ADC2_CH5)
N_MOSI: J7.3 (CMD), S0.16 (MTCK/GPIO13/ADC2_CH4), S1.16 (MTCK/GPIO13/ADC2_CH4), U3.16 (MTCK/GPIO13/ADC2_CH4)
N_RTS: Q1.2 (E), R4.1, U5.24 (~RTS)
N_RX: U3.35 (U0TXD/GPIO1), U5.26 (TXD)
N_SCLK: J7.5 (CLK), S0.13 (MTMS/GPIO14/ADC2_CH6), S1.13 (MTMS/GPIO14/ADC2_CH6), U3.13 (MTMS/GPIO14/ADC2_CH6)
N_TX: U3.34 (U0RXD/GPIO3), U5.25 (RXD)
N_VBUS: D2.2 (A), J1.1 (VBUS), R5.2
N_VDD33: C8.1, C9.1, C11.1, C34.1, C35.1, J4.1, J4.2, J7.4 (VDD), R7.1, R27.1, U1.2 (VO), U3.2 (3V3), U5.6 (VDD), U5.7 (VREGIN)
unnamed: D1.2 (A), R2.2
unnamed: D3.2 (A), J5.1
unnamed: D7.2 (A), S0.8 (32K_XP/GPIO32/ADC1_CH4)
unnamed: D7.1 (K), R18.1
unnamed: D8.2 (A), U3.8 (32K_XP/GPIO32/ADC1_CH4)
unnamed: D8.1 (K), R26.1
unnamed: D10.2 (A), S1.8 (32K_XP/GPIO32/ADC1_CH4)
unnamed: D10.1 (K), R28.1
unnamed: J1.3 (D+), U4.1, U5.4 (D+)
unnamed: J1.2 (D-), U4.2, U5.5 (D-)
unnamed: J2.3 (D+), U14.1, U15.4 (D+)
unnamed: J2.2 (D-), U14.2, U15.5 (D-)
unnamed: J3.3 (D+), U9.1, U10.4 (D+)
unnamed: J3.2 (D-), U9.2, U10.5 (D-)
unnamed: Q1.1 (B), R3.2
unnamed: Q2.1 (B), R4.2
unnamed: Q3.1 (B), R11.2
unnamed: Q4.1 (B), R12.2
unnamed: Q5.1 (B), R19.2
unnamed: Q6.1 (B), R20.2
unnamed: C30.2, S0.6 (GPIO34/ADC1_CH6), SW9.2
unnamed: C28.2, S1.6 (GPIO34/ADC1_CH6), SW7.2
unnamed: C32.2, SW10.2, U3.6 (GPIO34/ADC1_CH6)
unnamed: R5.1, R6.2, U5.8 (VBUS)
unnamed: R7.2, U5.9 (~RST)
unnamed: R8.1, U5.11 (~SUSPEND)
unnamed: R13.1, R14.2, U10.8 (VBUS)
unnamed: R15.2, U10.9 (~RST)
unnamed: R16.1, U10.11 (~SUSPEND)
unnamed: R21.1, R22.2, U15.8 (VBUS)
unnamed: R23.2, U15.9 (~RST)
unnamed: R24.1, U15.11 (~SUSPEND)
PHY_POWER: J4.13, R25.1, U3.29 (GPIO5)
RX0: J4.10, U3.10 (DAC_1/ADC2_CH8/GPIO25)
RX1: J4.9, U3.11 (DAC_2/ADC2_CH9/GPIO26)
RXCLK: J4.8, U3.28 (GPIO17)
S0_CS_0: S0.29 (GPIO5), S0_Comp_0.8
S0_CS_1: S0.33 (GPIO21), S0_Comp_1.8
S0_CS_2: S0.36 (GPIO22), S0_Comp_2.8
S0_CS_3: S0.10 (DAC_1/ADC2_CH8/GPIO25), S0_Comp_3.8
S0_CS_SD: J8.2 (DAT3/CD), S0.26 (ADC2_CH0/GPIO4)
S0_DTR: Q4.2 (E), R11.1, U10.28 (~DTR)
S0_EN: C10.2, C12.2, Q3.3 (C), R9.2, S0.3 (EN/CHIP_PU), SW3.2
S0_HS_0: S0.4 (SENSOR_VP/GPIO36/ADC1_CH0), S0_Comp_0.10
S0_HS_1: S0.5 (SENSOR_VN/GPIO39/ADC1_CH3), S0_Comp_1.10
S0_HS_2: S0.11 (DAC_2/ADC2_CH9/GPIO26), S0_Comp_2.10
S0_HS_3: S0.12 (ADC2_CH7/GPIO27), S0_Comp_3.10
S0_IO0: C14.2, Q4.3 (C), S0.25 (GPIO0/BOOT/ADC2_CH1), SW4.2
S0_MISO: J8.7 (DAT0), S0.31 (GPIO19), S0_Comp_0.4, S0_Comp_1.4, S0_Comp_2.4, S0_Comp_3.4
S0_MOSI: J8.3 (CMD), S0.37 (GPIO23), S0_Comp_0.2, S0_Comp_1.2, S0_Comp_2.2, S0_Comp_3.2
S0_RTS: Q3.2 (E), R12.1, U10.24 (~RTS)
S0_RX: S0.35 (U0TXD/GPIO1), U10.26 (TXD)
S0_SCLK: J8.5 (CLK), S0.30 (GPIO18), S0_Comp_0.6, S0_Comp_1.6, S0_Comp_2.6, S0_Comp_3.6
S0_TX: S0.34 (U0RXD/GPIO3), U10.25 (RXD)
S0_VBUS: D4.2 (A), J3.1 (VBUS), R13.2
S0_VDD33: C13.1, C15.1, C17.1, C18.1, C20.1, J8.4 (VDD), R9.1, R15.1, S0.2 (3V3), U2.2 (VO), U10.6 (VDD), U10.7 (VREGIN)
S1_CS_0: S1.29 (GPIO5), S1_Comp_0.8
S1_CS_1: S1.33 (GPIO21), S1_Comp_1.8
S1_CS_2: S1.36 (GPIO22), S1_Comp_2.8
S1_CS_3: S1.10 (DAC_1/ADC2_CH8/GPIO25), S1_Comp_3.8
S1_CS_SD: J6.2 (DAT3/CD), S1.26 (ADC2_CH0/GPIO4)
S1_DTR: Q6.2 (E), R19.1, U15.28 (~DTR)
S1_EN: C19.2, C21.2, Q5.3 (C), R17.2, S1.3 (EN/CHIP_PU), SW5.2
S1_HS_0: S1.4 (SENSOR_VP/GPIO36/ADC1_CH0), S1_Comp_0.10
S1_HS_1: S1.5 (SENSOR_VN/GPIO39/ADC1_CH3), S1_Comp_1.10
S1_HS_2: S1.11 (DAC_2/ADC2_CH9/GPIO26), S1_Comp_2.10
S1_HS_3: S1.12 (ADC2_CH7/GPIO27), S1_Comp_3.10
S1_IO0: C23.2, Q6.3 (C), S1.25 (GPIO0/BOOT/ADC2_CH1), SW6.2
S1_MISO: J6.7 (DAT0), S1.31 (GPIO19), S1_Comp_0.4, S1_Comp_1.4, S1_Comp_2.4, S1_Comp_3.4
S1_MOSI: J6.3 (CMD), S1.37 (GPIO23), S1_Comp_0.2, S1_Comp_1.2, S1_Comp_2.2, S1_Comp_3.2
S1_RTS: Q5.2 (E), R20.1, U15.24 (~RTS)
S1_RX: S1.35 (U0TXD/GPIO1), U15.26 (TXD)
S1_SCLK: J6.5 (CLK), S1.30 (GPIO18), S1_Comp_0.6, S1_Comp_1.6, S1_Comp_2.6, S1_Comp_3.6
S1_TX: S1.34 (U0RXD/GPIO3), U15.25 (RXD)
S1_VBUS: D6.2 (A), J2.1 (VBUS), R21.2
S1_VDD33: C22.1, C24.1, C26.1, C27.1, C31.1, J6.4 (VDD), R17.1, R23.1, S1.2 (3V3), U6.2 (VO), U15.6 (VDD), U15.7 (VREGIN)
TX0: J4.11, U3.31 (GPIO19)
TX1: J4.14, U3.36 (GPIO22)
TX_EN: J4.12, U3.33 (GPIO21)

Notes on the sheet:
Power Supply
Microcontroller
Designed by Team 20
USB to UART
Push Buttons
Compute Node Connections
Power Supply
Serial No. BNCCMBM
Switch 0
Switch 1
02/16/2025
Network
BoilerNet Compute Cluster - MicroUSB Compute Cluster Motherboard
LAN8720 Connection
Purdue University - ECE49022 Spring 2025

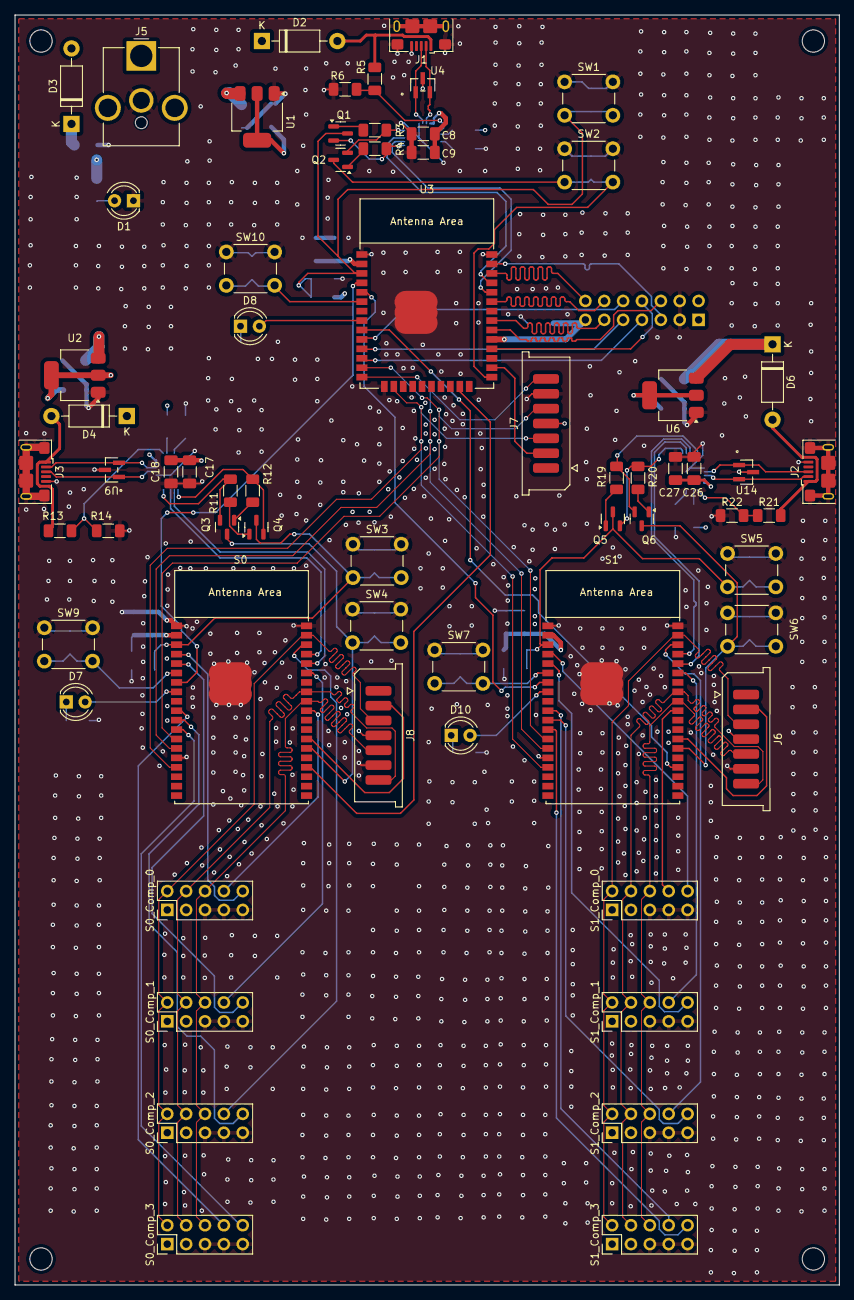
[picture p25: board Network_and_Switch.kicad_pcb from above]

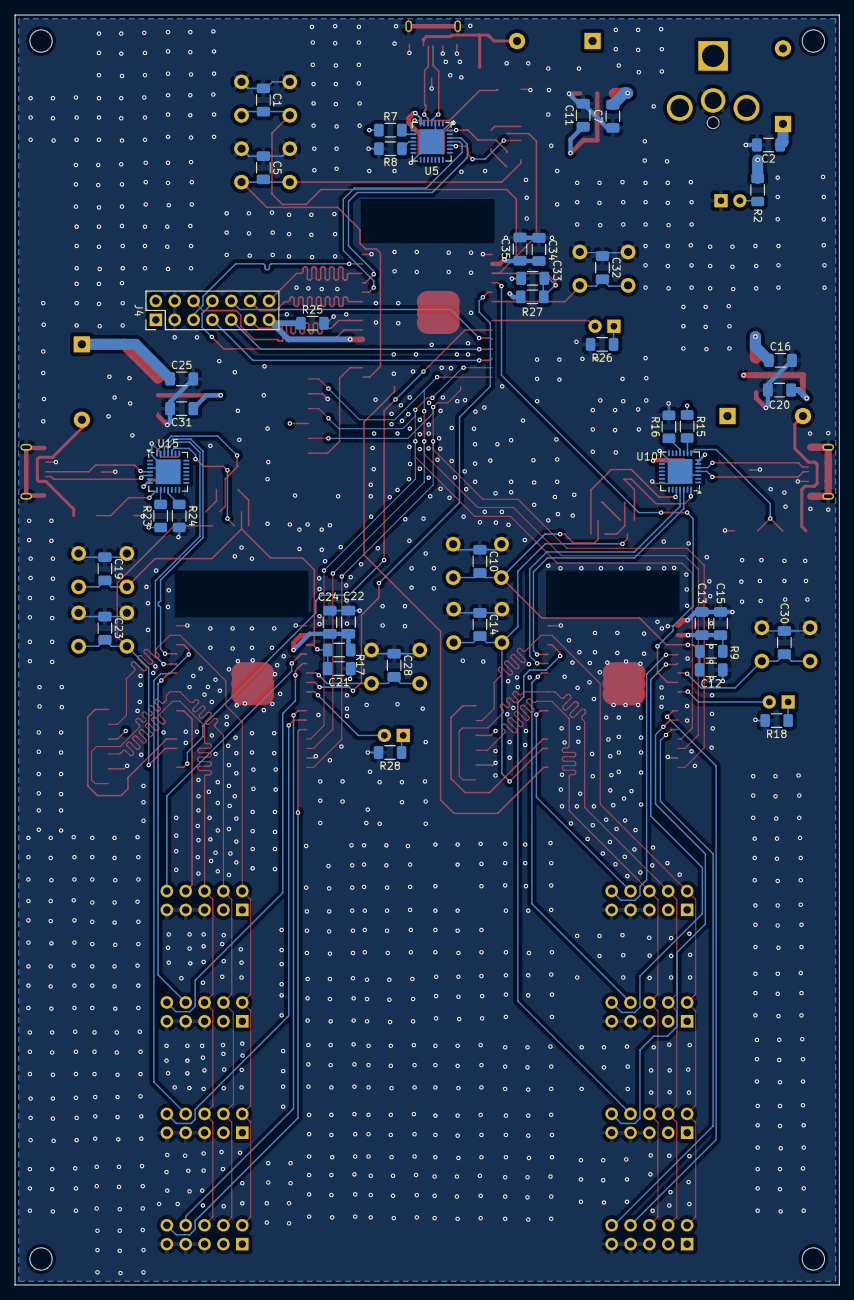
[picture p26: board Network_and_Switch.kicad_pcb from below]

Board: 4 copper layers, 111.0 x 171.0 mm, 108 parts (43 on the bottom side), 100 nets.

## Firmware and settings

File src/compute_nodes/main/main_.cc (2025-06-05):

#include "main.h"
#include <cmath>       // for lroundf
#include <algorithm>   // for clamp

// ##############################################################################

void turn_on() { 
  vTaskDelay(pdMS_TO_TICKS(10));
  gpio_set_level(BLINK_GPIO, 1);  
}


void turn_off() { 
  vTaskDelay(pdMS_TO_TICKS(10));
  gpio_set_level(BLINK_GPIO, 0);  
}

static void configure_led(void)
{
    gpio_config_t led_conf = {
        .pin_bit_mask = BIT64((gpio_num_t)BLINK_GPIO),   
        .mode         = GPIO_MODE_OUTPUT,                
        .pull_up_en   = GPIO_PULLUP_DISABLE,             
        .pull_down_en = GPIO_PULLDOWN_DISABLE,           
        .intr_type    = GPIO_INTR_DISABLE,               
    };
    gpio_config(&led_conf);
}

// ##############################################################################

void my_post_setup_cb(spi_slave_transaction_t *trans) {
    gpio_set_level(GPIO_HANDSHAKE, 1);
}
void my_post_trans_cb(spi_slave_transaction_t *trans) {
    gpio_set_level(GPIO_HANDSHAKE, 0);
}
void handshake_init_slave(void) {
    gpio_config_t io_conf = {
        .pin_bit_mask = (1ULL << GPIO_HANDSHAKE),
        .mode         = GPIO_MODE_OUTPUT,
        .pull_up_en   = GPIO_PULLUP_DISABLE,
        .pull_down_en = GPIO_PULLDOWN_DISABLE,
        .intr_type    = GPIO_INTR_DISABLE
    };
    gpio_config(&io_conf);
}

// ##############################################################################

esp_err_t spi_slave_init(void) {
    handshake_init_slave();

    spi_bus_config_t buscfg = {
        .mosi_io_num   = GPIO_MOSI,
        .miso_io_num   = GPIO_MISO,
        .sclk_io_num   = GPIO_SCLK,
        .quadwp_io_num = -1,
        .quadhd_io_num = -1,
        .max_transfer_sz = TRANSFER_SIZE,
    };
    spi_slave_interface_config_t slvcfg = {
        .spics_io_num   = GPIO_CS,
        .flags          = 0,
        .queue_size     = 3,
        .mode           = 0,
        .post_setup_cb  = my_post_setup_cb,
        .post_trans_cb  = my_post_trans_cb
    };
    gpio_set_pull_mode(GPIO_MOSI, GPIO_PULLUP_ONLY);
    gpio_set_pull_mode(GPIO_SCLK, GPIO_PULLUP_ONLY);
    gpio_set_pull_mode(GPIO_CS,   GPIO_PULLUP_ONLY);

    return spi_slave_initialize(HSPI_HOST, &buscfg, &slvcfg, SPI_DMA_CH_AUTO);
}


// ##############################################################################

void blade_spi_task(void *pvParameters) {
    uint8_t *rx_buf = reinterpret_cast<uint8_t*>(spi_bus_dma_memory_alloc(HSPI_HOST, TRANSFER_SIZE, 0));
    uint8_t *tx_buf = reinterpret_cast<uint8_t*>(spi_bus_dma_memory_alloc(HSPI_HOST, TRANSFER_SIZE, 0));
    blade_fsm_t fsm = BLADE_FSM_WAIT_START;
    uint8_t *png_buf = nullptr;
    uint8_t *rgba_ps = nullptr; 
    size_t png_len = 0;
    uint8_t *result_buf = nullptr;
    size_t  result_len = 0;
    int64_t t0 = 0;
    int64_t t1 = 0; 
    int64_t t2 = 0;
    int64_t t3 = 0; 
    int64_t t4 = 0;
    int64_t t5 = 0; 
    uint8_t* rgba = nullptr;
    uint8_t count = 0; 
    unsigned w,h;
    unsigned err; 

    turn_off();
    turn_on(); 
    const tflite::Model* model = tflite::GetModel(model_tflite);

    static tflite::MicroMutableOpResolver<6> resolver;  
    resolver.AddFullyConnected();
    resolver.AddSoftmax();
    resolver.AddConv2D();
    resolver.AddMean();
    resolver.AddDepthwiseConv2D();
    resolver.AddAdd();

    uint8_t* tensor_arena = (uint8_t*)heap_caps_malloc(TENSOR_ARENA_SZ, MALLOC_CAP_SPIRAM);

    tflite::MicroInterpreter interpreter(model, resolver, tensor_arena, TENSOR_ARENA_SZ, nullptr, nullptr);

    ESP_LOGI(COMM_TAG, "Max internal used: %u", heap_caps_get_largest_free_block(MALLOC_CAP_8BIT));

    if (interpreter.AllocateTensors() != kTfLiteOk) {
      ESP_LOGE(COMM_TAG, "AllocateTensors() failed");
      return;
    }

    spi_slave_transaction_t t_recv = {0};
    t_recv.length = TRANSFER_SIZE * 8;

    while (1) {
        memset(rx_buf, 0, TRANSFER_SIZE);

        turn_off();

        ESP_LOGI(COMM_TAG, "%d: Sending buffer; first bytes: 0x%02X 0x%02X 0x%02X 0x%02X ... 0x%02X 0x%02X", 
                 count, tx_buf[0], tx_buf[1], tx_buf[2], tx_buf[3], 
                 tx_buf[TRANSFER_SIZE - 2], tx_buf[TRANSFER_SIZE - 1]);


        t_recv.tx_buffer = tx_buf;
        t_recv.rx_buffer = rx_buf;

        esp_err_t ret = spi_slave_transmit(HSPI_HOST, &t_recv, portMAX_DELAY);
        if (ret != ESP_OK) {
            ESP_LOGE(COMM_TAG, "Receive transaction failed: %s", esp_err_to_name(ret));
            continue;
        }

        ESP_LOGI(COMM_TAG, "%d: Received buffer; first bytes: 0x%02X 0x%02X 0x%02X 0x%02X ... 0x%02X 0x%02X", 
                 count, rx_buf[0], rx_buf[1], rx_buf[2], rx_buf[3], 
                 rx_buf[TRANSFER_SIZE - 2], rx_buf[TRANSFER_SIZE - 1]);

        // ##########################################################
        
        uint8_t pkt = rx_buf[0];

        switch (fsm) {
            case BLADE_FSM_WAIT_START:
            {
              ESP_LOGI(COMM_TAG, "IN BLADE_FSM_WAIT_START");
              if (pkt == PACKET_TYPE_START_DATA_TO_BLADE)
              {
                ESP_LOGI(COMM_TAG, "START_DATA_TO_BLADE");

                size_t free_int = heap_caps_get_free_size(MALLOC_CAP_8BIT);
                size_t free_psr = heap_caps_get_free_size(MALLOC_CAP_SPIRAM);
                ESP_LOGI(COMM_TAG, "BLADE_FSM_WAIT_START, starting receive:  internal free=%u, psram free=%u", (unsigned)free_int, (unsigned)free_psr);

                const uint32_t PSRAM_ALIGN = cache_hal_get_cache_line_size(0, CACHE_TYPE_DATA);
                ESP_LOGI(COMM_TAG, "align=%u", (unsigned)PSRAM_ALIGN);

                png_buf = (uint8_t *)heap_caps_aligned_alloc(32, BUF_SIZE, MALLOC_CAP_SPIRAM | MALLOC_CAP_8BIT);
                if (!png_buf)
                {
                  ESP_LOGE(COMM_TAG, "Failed to alloc PSRAM for PNG buffer");
                  continue;
                }
                else
                {
                  ESP_LOGW(COMM_TAG, "PNGBUF made!");
                }
                png_len = 0;
                t0 = esp_timer_get_time();
                fsm = BLADE_FSM_RECEIVE;
                memcpy(tx_buf, rx_buf, TRANSFER_SIZE);
              }
              else if (pkt == PACKET_TYPE_FUC)
              {
                fsm = BLADE_FSM_ERROR;
              }
              else if (pkt == PACKET_TYPE_GET_RESULT_FROM_BLADE) { 
                if (tx_buf[0] == PACKET_TYPE_GET_RESULT_FROM_BLADE) memset(tx_buf, 0, TRANSFER_SIZE);
                else { 
                  ESP_LOGE(COMM_TAG, "In BLADE_FSM_WAIT_START, tx_buf doesn't have the result, but switch asked for a result: 0x%02X", pkt);
                  fsm = BLADE_FSM_ERROR;
                }
              } else {
                ESP_LOGE(COMM_TAG, "Got wrong Packet while in BLADE_FSM_WAIT_START: 0x%02X", pkt);
                fsm = BLADE_FSM_ERROR;
              }
                break;
            }
            case BLADE_FSM_RECEIVE:
            {
              ESP_LOGI(COMM_TAG, "IN BLADE_FSM_RECEIVE");

                if (pkt == PACKET_TYPE_FUC) {
                    fsm = BLADE_FSM_ERROR;
                    break;
                }
                if ((pkt == PACKET_TYPE_DATA_TO_BLADE) || (pkt == PACKET_TYPE_END_DATA_TO_BLADE)) {
                    int len = (rx_buf[1]<<8)|rx_buf[2];

                    ESP_LOGI(COMM_TAG, "In RECEIVE: Got %d bytes", len);

                    if (png_len + len > BUF_SIZE) {
                      ESP_LOGE(COMM_TAG, "PNG buffer overflow: have %u, need %d", (unsigned)png_len, len);
                      fsm = BLADE_FSM_ERROR;
                      break;
                    }

                    if (!png_buf) { 
                      ESP_LOGE(COMM_TAG, "PNG Buf is not even made!!");
                      fsm = BLADE_FSM_ERROR;
                      break; 
                    } 
                    
                    memcpy(png_buf + png_len, rx_buf + 3, len);
                    png_len += len;
                    memcpy(tx_buf, rx_buf, TRANSFER_SIZE);

                    if (pkt == PACKET_TYPE_END_DATA_TO_BLADE) {
                      t1 = esp_timer_get_time();
                      ESP_LOGI(COMM_TAG, "SPI recv %d bytes in %lld ms", png_len, (t1 - t0) / 1000);
                      fsm = BLADE_FSM_PROCESS; // DIRECTLY GO into BLADE_FSM_PROCESS; 
                    }
                    else
                    {
                      break;
                    }
                } else if (pkt == PACKET_TYPE_FUC) {
                    fsm = BLADE_FSM_ERROR; 
                  break;
                }  else {
                    ESP_LOGE(COMM_TAG, "Got wrong Packet while in BLADE_FSM_RECEIVE: 0x%02X", pkt);
                  fsm = BLADE_FSM_ERROR;
                  break;
                }

            }
            case BLADE_FSM_PROCESS:
            {
              ESP_LOGI(COMM_TAG, "In BLADE_FSM_PROCESS; BEGINNING PROCESSING!");
              if (pkt == PACKET_TYPE_FUC)
              {
                fsm = BLADE_FSM_ERROR;
                break;
              }
                turn_on(); 

                t2 = esp_timer_get_time();

                ESP_LOGI(COMM_TAG, "HEADER: %d, %d, %d, %d, %d, %d, %d, %d", png_buf[0], png_buf[1], png_buf[2], png_buf[3], png_buf[4], png_buf[5], png_buf[6], png_buf[7]);
                err = lodepng_decode32(&rgba, &w, &h, png_buf, png_len);
                t3 = esp_timer_get_time();
                if (err || w!=IMG_SIZE || h!=IMG_SIZE) {
                    if (err) ESP_LOGE(COMM_TAG, "PNG decode error %u: %s", err, lodepng_error_text(err));
                    else ESP_LOGE(COMM_TAG, "PNG decode error, not err, but the h, w problem | %d, %d | %u: %s", h, w, err, lodepng_error_text(err));
                    fsm = BLADE_FSM_ERROR;
                    break;
                }

                ESP_LOGI(COMM_TAG, "PNG decode in %lld ms", (t3-t2)/1000);

                // memset(tensor_arena, 0, TENSOR_ARENA_SZ);

                size_t img_bytes = w * h * 4;
                rgba_ps = (uint8_t*)heap_caps_malloc(img_bytes, MALLOC_CAP_SPIRAM|MALLOC_CAP_8BIT);
                if (!rgba_ps) {
                    ESP_LOGE(COMM_TAG, "PSRAM alloc failed for RGBA");
                    free(rgba);
                    break;
                }
                memcpy(rgba_ps, rgba, img_bytes);
                free(rgba);
                heap_caps_free(png_buf);

                TfLiteTensor* input = interpreter.input(0);
                float scale_in    = input->params.scale;
                int   zp_in       = input->params.zero_point;
                ESP_LOGI(COMM_TAG, "INPUT quant params → scale=%.6f, zero_pt=%d", scale_in, zp_in);


                t4 = esp_timer_get_time();

                int8_t* in_data_ptr = input->data.int8;
                auto quantize = [&](float v)->int8_t {
                  float qf = v/scale_in + zp_in;
                  int qi   = std::lround(qf);
                  qi = std::clamp(qi, -128, 127);
                  return static_cast<int8_t>(qi);
                };

                for (int y = 0; y < h; y++) {
                  for (int x = 0; x < w; x++) {
                    int rgba_idx = (y*w + x)*4;
                    int rgb_idx  = (y*w + x)*3;
                    float rf = rgba_ps[rgba_idx + 0] / 255.f;
                    float gf = rgba_ps[rgba_idx + 1] / 255.f;
                    float bf = rgba_ps[rgba_idx + 2] / 255.f;
                    in_data_ptr[rgb_idx + 0] = quantize(rf*2.f - 1.f);
                    in_data_ptr[rgb_idx + 1] = quantize(gf*2.f - 1.f);
                    in_data_ptr[rgb_idx + 2] = quantize(bf*2.f - 1.f);
                  }
                }
                // Print first few quantized values for manual cross-check
                ESP_LOGI(COMM_TAG, "in_data[0..5] = %d, %d, %d, %d, %d, %d",
                        in_data_ptr[0], in_data_ptr[1], in_data_ptr[2],
                        in_data_ptr[3], in_data_ptr[4], in_data_ptr[5]);


                if (interpreter.Invoke() != kTfLiteOk) {
                    ESP_LOGE(COMM_TAG, "Invoke failed");
                    fsm = BLADE_FSM_ERROR;
                    break;
                }

                t5 = esp_timer_get_time();
                long long int total_time = (t5 - t4) / 1000; 
                ESP_LOGI(COMM_TAG, "Inference in %lld ms", total_time);

                TfLiteTensor* output = interpreter.output(0);
                const float scale_out = output->params.scale;
                const int   zp_out    = output->params.zero_point;
                ESP_LOGI(COMM_TAG, "OUTPUT quant params → scale=%.6f, zero_pt=%d", scale_out, zp_out);

                // 8) Extract raw & dequantized outputs
                int8_t* out_data_ptr = output->data.int8;
                ESP_LOGI(COMM_TAG, "raw out_data: %d, %d, %d, %d, %d",
                        out_data_ptr[0], out_data_ptr[1],
                        out_data_ptr[2], out_data_ptr[3],
                        out_data_ptr[4]);  // adjust if >5 classes


                float confidences[NUM_CLASSES];
                for (int i = 0; i < NUM_CLASSES; i++) {
                  confidences[i] = (out_data_ptr[i] - zp_out) * scale_out;
                  ESP_LOGI(COMM_TAG,
                          "class %2d: raw=%4d → conf=%.4f",
                          i, out_data_ptr[i], confidences[i]);
                }

                int best = std::distance(
                  confidences,
                  std::max_element(confidences, confidences + NUM_CLASSES)
                );
                ESP_LOGI(COMM_TAG, "Best index=%d (%s)", best, model_labels[best]);

                const char* res = model_labels[best];
                ESP_LOGI(COMM_TAG, "Result: %s", res);

                memset(tx_buf, 0, TRANSFER_SIZE);
                tx_buf[0] = PACKET_TYPE_GET_RESULT_FROM_BLADE;

                char* p = (char*)(tx_buf + 3);
                int pos = 0;

                pos += snprintf(p + pos, TRANSFER_SIZE - 3 - pos,
                    "{"
                      "\"pred\":\"%s\","
                      "\"time\":%lld,"
                      "\"scores\":{",
                    model_labels[best],
                    total_time
                );

                for (int i = 0; i < NUM_CLASSES; i++) {
                  pos += snprintf(p + pos, TRANSFER_SIZE - 3 - pos,
                  "\"%s\":%.3f%s",
                  model_labels[i],
                  confidences[i],
                  (i < NUM_CLASSES - 1) ? "," : ""
                  );
                }

                pos += snprintf(p + pos, TRANSFER_SIZE - 3 - pos, "}}\n");

                tx_buf[1] = (pos >> 8) & 0xFF;
                tx_buf[2] = (pos     ) & 0xFF;

                fsm = BLADE_FSM_WAIT_START;
                turn_off();
                break;
            }
            default: {
                fsm = BLADE_FSM_ERROR;
                memset(tx_buf, 0, TRANSFER_SIZE);
                tx_buf[0] = PACKET_TYPE_FUC;
                ESP_LOGE(COMM_TAG, "FSM ERROR, don't know what command is sent");
                break;
            }
        }

        if (fsm == BLADE_FSM_ERROR) {
            ESP_LOGE(COMM_TAG, "BLADE FSM ERROR!");
            if (png_buf) { 
              heap_caps_free(png_buf);
            }
            if (rgba) { 
              free(rgba);
            } 
            png_buf = nullptr;
            rgba = nullptr; 
            fsm = BLADE_FSM_WAIT_START;
            tx_buf[0] = PACKET_TYPE_FUC;
            t0 = 0;
            t1 = 0;
            t2 = 0;
            t3 = 0;
            t4 = 0;
            t5 = 0;
            png_len = 0;
            turn_off();
        } 
        count = (count == 1) ? 0 : 1;
    }
}

// ##############################################################################

extern "C" void app_main() {
    configure_led(); 

    esp_err_t ret = spi_slave_init(); 
    if (ret != ESP_OK)
    {
        ESP_LOGE(COMM_TAG, "SPI SLAVE INITIALIZATION FAILED!: %s", esp_err_to_name(ret));
        return;
    }
    
    xTaskCreate(blade_spi_task, "blade_spi", 8*1024, NULL, 5, NULL);
    ESP_LOGI(COMM_TAG, "BLADE HANDLER INITIALIZED!");

    for (int i=1; i<NUM_CLASSES; ++i) {
      const char* res = model_labels[i];
      ESP_LOGI(COMM_TAG, "Class Name: %s", res);
    }


}

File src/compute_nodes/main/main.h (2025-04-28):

#include <stdio.h>
#include <string.h>
#include "freertos/FreeRTOS.h"
#include "freertos/task.h"
#include "esp_log.h"
#include "esp_err.h"
#include "esp_timer.h"
#include "sdkconfig.h"
#include "lodepng.h"
#include "esp_heap_caps.h"

extern "C" {
  #include "driver/gpio.h"
  #include "driver/spi_slave.h"
  #include "hal/cache_hal.h"    
}

// TFLM includes
#include "tensorflow/lite/micro/micro_mutable_op_resolver.h"
#include "tensorflow/lite/micro/micro_interpreter.h"
#include "tensorflow/lite/schema/schema_generated.h"

// Model header (const array lives in Flash/RODATA)
#include "model_data.h"

#define BLINK_GPIO GPIO_NUM_32


#define GPIO_MOSI    GPIO_NUM_13
#define GPIO_MISO    GPIO_NUM_12
#define GPIO_SCLK    GPIO_NUM_14
#define GPIO_CS      GPIO_NUM_15

#define GPIO_HANDSHAKE GPIO_NUM_2
#define TRANSFER_SIZE   2048
#define COMM_TAG  "BLADE_SPI"

#define PACKET_TYPE_START_DATA_TO_BLADE   0xD0
#define PACKET_TYPE_DATA_TO_BLADE         0xD1
#define PACKET_TYPE_END_DATA_TO_BLADE     0xD2
#define PACKET_TYPE_GET_RESULT_FROM_BLADE 0xD3
#define PACKET_TYPE_CLEAR_BLADE 0xDF

#define PACKET_TYPE_FUC   0xA4

typedef enum {
    BLADE_FSM_WAIT_START,
    BLADE_FSM_RECEIVE,
    BLADE_FSM_PROCESS,
    BLADE_FSM_ERROR
} blade_fsm_t;

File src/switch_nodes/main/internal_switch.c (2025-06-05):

#include "internal_switch.h"

// ##############################################################################

void led_on() { 
  vTaskDelay(pdMS_TO_TICKS(2));
  gpio_set_level(LED_NUM, 1);  
}


void led_off() { 
  vTaskDelay(pdMS_TO_TICKS(2));
  gpio_set_level(LED_NUM, 0);  
}

static void configure_led(void)
{
    gpio_config_t led_conf = {
        .pin_bit_mask = (1ULL << LED_NUM),   
        .mode         = GPIO_MODE_OUTPUT,                
        .pull_up_en   = GPIO_PULLUP_DISABLE,             
        .pull_down_en = GPIO_PULLDOWN_DISABLE,           
        .intr_type    = GPIO_INTR_DISABLE,               
    };
    gpio_config(&led_conf);
}

// ##############################################################################

void my_post_setup_cb(spi_slave_transaction_t *trans)
{
    gpio_set_level(NETWORK_HANDSHAKE, 1);
}

void my_post_trans_cb(spi_slave_transaction_t *trans)
{
    gpio_set_level(NETWORK_HANDSHAKE, 0);
}

void handshake_init_slave(void)
{
    gpio_config_t io_conf = {
        .intr_type = GPIO_INTR_DISABLE,
        .mode = GPIO_MODE_OUTPUT,
        .pin_bit_mask = (1ULL << NETWORK_HANDSHAKE),
        .pull_down_en = GPIO_PULLDOWN_DISABLE,
        .pull_up_en = GPIO_PULLUP_DISABLE,
    };
    gpio_config(&io_conf);
}

static esp_err_t spi_slave_init(void)
{
    esp_err_t ret;

    handshake_init_slave();

    spi_bus_config_t buscfg = {
        .mosi_io_num = NETWORK_MOSI,
        .miso_io_num = NETWORK_MISO,
        .sclk_io_num = NETWORK_SCLK,
        .quadwp_io_num = -1,
        .quadhd_io_num = -1,
        .max_transfer_sz = TRANSFER_SIZE,
    };

    spi_slave_interface_config_t slvcfg = {
        .mode = 0,
        .spics_io_num = NETWORK_CS,
        .queue_size = 2,
        .flags = 0,
        .post_setup_cb = my_post_setup_cb,
        .post_trans_cb = my_post_trans_cb
    };

    gpio_set_pull_mode(NETWORK_MOSI, GPIO_PULLUP_ONLY);
    gpio_set_pull_mode(NETWORK_SCLK, GPIO_PULLUP_ONLY);
    gpio_set_pull_mode(NETWORK_CS,   GPIO_PULLUP_ONLY);

    ret = spi_slave_initialize(NETWORK_HOST, &buscfg, &slvcfg, SPI_DMA_CH_AUTO);
    return ret; 
}

// ##############################################################################

static esp_err_t SDCardInit(void) {
    esp_vfs_fat_sdmmc_mount_config_t mount_config = {
        .format_if_mount_failed = true,
        .max_files = 5,
        .allocation_unit_size = 16 * 1024
    };

    sdmmc_card_t *card;
    const char mount_point[] = MOUNT_POINT;
    sdmmc_host_t host = SDSPI_HOST_DEFAULT();
    host.slot = SD_HOST; 

    spi_bus_config_t bus_cfg = {
        .mosi_io_num = SD_NUM_MOSI,
        .miso_io_num = SD_NUM_MISO,
        .sclk_io_num = SD_NUM_CLK,
        .quadwp_io_num = -1,
        .quadhd_io_num = -1,
        .max_transfer_sz = 2048,
    };

    host.max_freq_khz = 5200;
    int ret = spi_bus_initialize(host.slot, &bus_cfg, SDSPI_DEFAULT_DMA);
    if (ret != ESP_OK) {
        ESP_LOGE("SDCARD", "Failed to initialize SPI bus for SD card: %s", esp_err_to_name(ret));
        return ret;
    }

    sdspi_device_config_t slot_config = SDSPI_DEVICE_CONFIG_DEFAULT();
    slot_config.gpio_cs = SD_NUM_CS;
    slot_config.host_id = host.slot;

    ret = esp_vfs_fat_sdspi_mount(mount_point, &host, &slot_config, &mount_config, &card);
    if (ret != ESP_OK) {
        ESP_LOGE("SDCARD", "Failed to mount SD card: %s", esp_err_to_name(ret));
        return ret;
    }

    ESP_LOGI("SDCARD", "SD Card mounted at: %s", MOUNT_POINT);
    return ESP_OK;
}

static FILE *sdcard_open(const char *filename, const char *mode) {
    char path[128];
    snprintf(path, sizeof(path), "%s/%s", MOUNT_POINT, filename);
    return fopen(path, mode);
}

static size_t sdcard_write(FILE *file, const void *buffer, size_t size) {
    return fwrite(buffer, 1, size, file);
}

static int sdcard_read(FILE *file, void *buffer, size_t size) {
    if (file == NULL) {
        return -1;
    }
    size_t bytes_read = fread(buffer, 1, size, file);
    if (ferror(file)) {
        return -1;
    }
    return bytes_read;
}

static void sdcard_close(FILE *file) {
    fclose(file);
}

static void sdcard_delete(const char *filename) {
    char path[128];
    snprintf(path, sizeof(path), "%s/%s", MOUNT_POINT, filename);
    remove(path);
}

// ##############################################################################

esp_err_t compute_spi_master_init(void)
{

    spi_device_interface_config_t devcfg = {
        .clock_speed_hz  = 5000000,  // 1 MHz—tune to your blades’ needs
        .mode            = 0,
        .spics_io_num    = -1,               // will set per-device below
        .queue_size      = 1,
    };

    for (int i = 0; i < NUM_COMPUTE_BLADES; i++) {
        devcfg.spics_io_num = compute_cs_pins[i];
        esp_err_t ret = spi_bus_add_device(SD_HOST, &devcfg, &compute_handles[i]);
        if (ret != ESP_OK) {
            ESP_LOGW(COMM_TAG,                      "Blade %d not registered (CS pin %d): %s",                      i, compute_cs_pins[i], esp_err_to_name(ret));
        } else {
            ESP_LOGI(COMM_TAG,                      "Blade %d registered on CS pin %d",                      i, compute_cs_pins[i]);
        }
    }
    return ESP_OK;
}

void setup_compute_handshake_gpios(void)
{
    gpio_config_t io_conf = {
        .intr_type    = GPIO_INTR_DISABLE,
        .mode         = GPIO_MODE_INPUT,
        .pin_bit_mask = 0,
        .pull_down_en = GPIO_PULLDOWN_DISABLE,
        .pull_up_en   = GPIO_PULLUP_ENABLE,
    };
    for (int i = 0; i < NUM_COMPUTE_BLADES; i++) {
        io_conf.pin_bit_mask |= 1ULL << compute_handshake_pins[i];
    }
    gpio_config(&io_conf);
    ESP_LOGI(COMM_TAG, "Configured %d compute handshake GPIOs", NUM_COMPUTE_BLADES);
}

int find_available_compute_blades(void)
{
    int count = 0;
    for (int i = 0; i < NUM_COMPUTE_BLADES; i++) {
        int lvl = gpio_get_level(compute_handshake_pins[i]);
        if (lvl) {
            count++;
        } else {
            ESP_LOGW(COMM_TAG,                      "Blade %d not responding (HS pin %d low)",                      i, compute_handshake_pins[i]);
        }
    }
    ESP_LOGI(COMM_TAG,              "%d/%d compute blades available",              count, NUM_COMPUTE_BLADES);
    return count;
}

bool make_result_filename(const char *in, char *out, size_t out_sz) {
    const char *dot = strrchr(in, '.');
    size_t base_len = dot ? (size_t)(dot - in) : strlen(in);

    const char *suffix = "_results.txt";
    size_t suffix_len = strlen(suffix);

    if (base_len + suffix_len + 1 > out_sz) {
        return false;
    }

    for (size_t i = 0; i < base_len; i++) {
        out[i] = (char) tolower((unsigned char)in[i]);
    }
    memcpy(out + base_len, suffix, suffix_len + 1); 

    return true;
}
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

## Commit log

2025-02-05 Two way usb-uart
2025-03-05 updating with the fixed 2-step read/write logic
    [internal_switch.c, network_node.c]
2025-04-28 adding models
    [cats_mobilenet_v2.csv, dogs_mobilenet_v2.csv, fruits_mobilenet_v2.csv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]
